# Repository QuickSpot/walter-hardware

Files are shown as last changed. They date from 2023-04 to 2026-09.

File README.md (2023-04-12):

# Walter hardware

## Introduction

In this repository you can find all information about Walter's hardware. The
hardware is designed using KiCad but we also support Altium designer footprints.
Besides footprints you can also find:
 - Datasheets
 - 3D renders
 - Schematics

Datasheets are published as PDF and are constructed using LaTeX. We welcome any
pull request on the datasheets to make sure all information that is required is
present.

## License

All files in this repository are published under the GPLv3 license.

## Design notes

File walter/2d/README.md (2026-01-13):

# Walter 2D for Laser Cut / Housing Prototyping

This folder contains 2D vector files (in mm scale) to assist with laser cutting, CNC routing, or general housing design for the Walter module.

Included files represent the board’s physical outline and can be used to:
- Cut a mounting area or clearance in enclosures
- Add alignment or anchor features for Walter
- Integrate Walter into panel layouts or case designs

## Notes for Use
- All dimensions are in **millimeters (mm)**.
- Files are provided as **vector formats** (`.svg`, `.pdf`, `.dxf`) and should open in most CAD, vector, or laser software.
- You may need to adjust **cut/engrave/stroke settings** depending on your machine or fabrication provider.
  - Red hairlines (0.001 pt) are commonly used for cuts
  - Black fills or blue lines are typically used for engraving
- Always check alignment and scaling before running a final job.

## Related Footprint Info
Walter uses 2.54mm pitch headers with 14 pins per side (see `footprint/README.md` for full part details). The 2D outline does **not** include pin depths or socket clearance—verify fit based on your exact setup.

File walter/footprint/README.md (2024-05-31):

# Walter footprint

Walter uses 2.54mm pin headers with 14 pins on each side. The mounted part is 
Würth Elektronik 61001418221 with a 6mm pin height or a compatible part with 
slightly less high pins.

Walter can be soldered directly onto your design using wave soldering or by
making use of matching sockets. Possible sockets to use are:
 -  Würth Elektronik 61301411821
 -  Multicomp Pro 2212S-14SG-85
 -  Samtec SSW-114-01-T-S

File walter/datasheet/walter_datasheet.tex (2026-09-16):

\documentclass[11pt]{article}

\usepackage[margin=2cm, a4paper]{geometry}	%2cm page margin
\usepackage{fancyhdr}						%use fancy headers
\usepackage{graphicx}						%use images
\usepackage{textcomp}						%used for textdegree command
\usepackage[hidelinks]{hyperref}            %used for clickable references
\usepackage{pgfplots}
\usepackage{tikz}
\pgfplotsset{compat=1.18}

%DPTECHNICS datasheet variables
\newcommand{\dptproduct}{Walter - WiFi/BLE/NB-IoT/LTE-M/GNSS module}

\newcommand{\textoverline}[1]{$\overline{\mbox{#1}}$}

%page footers and headers settings
\pagestyle{fancy}
\fancyhead{}
\fancyfoot{}
\fancyhead[LO,LE]{ {\bf \dptproduct}}
\fancyfoot[R]{\thepage}
\fancyfoot[L]{QuickSpot - A brand of DPTechnics BV}
\renewcommand{\footrulewidth}{0.4pt}
\renewcommand\familydefault{\sfdefault}
\setlength{\parindent}{0pt}

\begin{document}
\begin{titlepage}
\hfill\\

\hfill {\bf \Large  \dptproduct}\\[-3mm]

\hfill {\Large Datasheet} \\[4cm]

\begin{center}
 
\end{center}

\vfill
\rule{487pt}{1pt}

\hfill Revision 1.0 - \today
\end{titlepage}
\section{General information}
Walter is a small-form-factor IoT system-on-module (SoM) that combines a powerful ESP32-S3 system-on-chip (SoC) with a second-generation Sequans GM02SP LTE-M/NB-IoT 5G modem and GNSS receiver. Its ESP32-S3 provides many built-in peripherals as well, including UART, SPI, I²C, CAN, Wi-Fi b/g/n, and Bluetooth 5.

\section{Features}
Walter is based on an ESP32-S3-WROOM-1-N16R2 module with an on-board Sequans GM02SP modem.
This combination makes Walter a unique development board that offers a rich feature-set which include but is not limited to:
\begin{itemize}
	\item CPU: Xtensa Dual-core 32-bit LX7 CPU (ESP32-S3 SoC)
	\item RAM: 2MB (Quad SPI) PSRAM
	\item Flash: 16MB (Quad SPI) Flash memory
	\item WiFi: 150Mbps(n) 802.11 WiFi b/g/n with on-board antenna
	\item LTE: CAT M1/NB1/NB2 (GM02SP module)
	\item GPS: GPS, GNSS Constellation support (GM02SP module)
	\item Bluetooth: 2Mbps Bluetooth 5 (LE), Bluetooth Mesh
	\item 24 physical GPIO pins
	\item Ultra low deep sleep current of 9.8\textmu A
	\item Open source software support for ESP-IDF, Arduino, Micropython and Toit
	\item Certified for CE, FCC, IC, UKCA, New-Zealand and Australia
	\item Solderless integration into any project due to the 2.54mm pin headers
\end{itemize}

\section{Electrical characteristics}
For the most reliable use and stability of the module we advice to use the typical ratings. We do not guarantee the correct functioning of the device outsite the minimum and maxium range of the module. 
\begin{center}
\renewcommand{\arraystretch}{1.5}
\begin{tabular}{|p{5cm}|c|c|c|c|}
\hline
{\bf Parameter} & {\bf Units} & {\bf Minimum rating} & {\bf Typical rating} & {\bf Maximum rating} \\
\hline
\hline
DC Supply Voltage & V & 3.0 & 5.0 & 5.5 \\
\hline
Digital I/O Voltage & V & 2.64 & 3.3 & 3.6 \\
\hline
Power consumption @3.3V & A & -- & -- & 1.5 \\
\hline
3.3V output current & A & -- & -- & 0.25 \\
\hline
Deep sleep current & \textmu A & -- & 9.8 & -- \\
\hline
\end{tabular}
\end{center}

\newpage
\section{Interfaces}
Walter provides a total of 28 physical pins (3 power, 1 strapping pin and 24 I/O pins) to interface with external parts. This chapter provides information about these pins as well as internally connected pins and the testpoints located at the bottom of the board.\\

Power supply pins and their details are available in section \ref{power} about the power characteristics.\\

For more information about specific pins regarding the ESP32-S3 Wroom module or the Sequans GM02SP module, please refer to the datasheet of the corresponding module.

\subsection{Pin Assignment} \label{pin_assigment}

\begin{figure}[h]
    \centering
    
    \caption{Walter pinout (top view)}
    \label{fig:walter_pin_assignment}
\end{figure}
\newpage
\subsubsection{External Pins} \label{external_pins}
Table \ref{table_exteral_pin} contains the description of the physical pins on Walter available on the underside of the board. \\
The order of this table, in reference to the board, is top to bottom and left to right.\\
\renewcommand{\arraystretch}{1.5}
\begin{table}[!h]
\begin{center}
\begin{tabular}{|c|c|c|c|c|p{9.5cm}|}
\hline
{\bf Pin} & {\bf Function} & \multicolumn{1}{c|}{\bf ESP pin} & \multicolumn{1}{c|}{\bf Input/Output} & \multicolumn{1}{c|}{\bf Description} \\
\hline
\hline
1 & RESET & EN & input & ESP32 reset with 10k pullup \\
\hline
2 & IO44/RX0 & RXD0 & bidirectional & ESP32 UART0 Receive \\
\hline
3 & IO43/TX0 & TXD0 & bidirectional & ESP32 UART0 Transmit \\
\hline
4 & \textoverline{DFU}/\textoverline{3V3\_EN} & IO0 & bidirectional & DFU when low on boot and 3V3 output enable \\
\hline
5 & IO12 & IO12 & bidirectional & General purpose I/O \\
\hline
6 & IO11 & IO11 & bidirectional & General purpose I/O \\
\hline
7 & IO13 & IO13 & bidirectional & General purpose I/O \\
\hline
8 & IO38 & IO38 & bidirectional & General purpose I/O \\
\hline
9 & IO39 & IO39 & bidirectional & General purpose I/O \\
\hline
10 & IO40 & IO40 & bidirectional & General purpose I/O \\
\hline
11 & IO41 & IO41 & bidirectional & General purpose I/O \\
\hline
12 & IO42 & IO42 & bidirectional & General purpose I/O \\
\hline
13 & IO2 & IO2 & bidirectional & General purpose I/O \\
\hline
14 & IO1 & IO1 & bidirectional & General purpose I/O \\
\hline
15 & IO4 & IO4 & bidirectional & General purpose I/O \\
\hline
16 & IO5 & IO5 & bidirectional & General purpose I/O \\
\hline
17 & IO6 & IO6 & bidirectional & General purpose I/O \\
\hline
18 & IO7 & IO7 & bidirectional & General purpose I/O \\
\hline
19 & IO15 & IO15 & bidirectional & General purpose I/O \\
\hline
20 & IO16 & IO16 & bidirectional & General purpose I/O \\
\hline
21 & IO17 & IO17 & bidirectional & General purpose I/O \\
\hline
22 & IO18 & IO18 & bidirectional & General purpose I/O \\
\hline
23 & IO8 & IO8 & bidirectional & General purpose I/O \\
\hline
24 & IO9 & IO9 & bidirectional & General purpose I/O \\
\hline
25 & IO10 & IO10 & bidirectional & General purpose I/O \\
\hline
26 & 3V3 OUT & N/A & power output & Switchable 3.3VDC output \\
\hline
27 & GND & GND & power ground & GND connection \\
\hline
28 & VIN & N/A & power input & DC Power input port\\
\hline
\end{tabular}
\caption{\label{table_exteral_pin}Walter pin definitions}
\end{center}
\end{table}
\newpage

\subsubsection{Internal Pins} \label{internal_pins}
Table \ref{table_interal_pin} contains the pin descriptions of the internally connected GPIO pins on Walter. These are necessary for either communication between components on the board or reserved for other purposes and thus not available for external use.

\begin{table}[!h]
    \centering
    \begin{tabular}{|c|p{9.5cm}|}
    \hline
    {\bf ESP pin} & \multicolumn{1}{c|}{\bf Description} \\
    \hline
    \hline
    IO19 & USB D-\\
    \hline
    IO20 & USB D+\\
    \hline
    IO46 & LTE\_WAKE0 \\
    \hline
    IO48 & LTE\_UART0\_TX (See \ref{lte_uart})\\
    \hline
    IO14 & LTE\_UART0\_RX (See \ref{lte_uart})\\
    \hline
    IO21 & LTE\_UART0\_RTS (See \ref{lte_uart})\\
    \hline
    IO47 & LTE\_UART0\_CTS (See \ref{lte_uart})\\
    \hline
    IO45 & LTE\_RESET\\
    \hline
    \end{tabular}
    \caption{\label{table_interal_pin}Walter Internal Pin Definitions}
\end{table}

\newpage
\subsubsection{Testpoints} \label{testpoints}
Walter contains 22 testpoints on the bottom of the board that serve multiple purposes. You can use these pins for debugging, interfacing and/or flashing of the Sequans GM02SP and the ESP32-S3-WROOM module.
\begin{figure}[h]
    \centering
    
    \caption{Walter testpoints}
    \label{fig:testpoints}
\end{figure}

\begin{center}
\begin{tabular}{|c|p{9.5cm}|}
    \hline
    {\bf Number} & \multicolumn{1}{c|}{\bf Description} \\
    \hline
    \hline
    1 & Sequans GM02SP JTAG TDO\\
    \hline
    2 & Sequans GM02SP JTAG TCK\\
    \hline
    3 & Sequans GM02SP JTAG TRSTN\\
    \hline
    4 & Sequans GM02SP JTAG TMS\\
    \hline
    5 & Sequans GM02SP JTAG TDI\\
    \hline
    6 & Sequans GM02SP PS status\\
    \hline
    7 & Sequans GM02SP RES/FFF\_FFH \\
    \hline
    8 & Sequans GM02SP RX0 \\
    \hline
    9 & Sequans GM02SP TX0 \\
    \hline
    10 & Sequans GM02SP TX1 \\
    \hline
    11 & Sequans GM02SP RX1 \\
    \hline
    12 & Sequans GM02SP RX2 \\
    \hline
    13 & Sequans GM02SP CTS0 \\
    \hline
    14 & Sequans GM02SP RTS0 \\ 
    \hline
    15 & Sequans GM02SP CTS1 \\
    \hline
    16 & Sequans GM02SP RTS1 \\
    \hline
    17 & Sequans GM02SP TX2 \\
    \hline
    18 & Walter input power \\
    \hline
    19 & 3V3 output (not switched) \\
    \hline
    20 & Sequans GM02SP 1V8 output \\
    \hline
    21 & Ground \\
    \hline
    22 & ESP32-S3 GPIO3 (strapping pin)\\
    \hline
\end{tabular}
\end{center}

\begin{figure}[h]
    \centering
    
    \caption{Bottom view of the Walter testpoints with their connection names.}
    \label{fig:testpointsnamed}
\end{figure}

\subsubsection{Others}
Not all pins of the ESP32-S3 and Sequans GM02SP on Walter are internally connected, available through physical pins or testpoints. These pins are either reserved for use by the component itself or deemed not necessary to be available externally.

\subsection{Sequans GM02SP UARTs} \label{lte_uart}
The Sequans GM02SP module has 3 hardware UART interfaces. Only UART0 is connected to the ESP32-S3 Wroom Module on Walter as shown in Table \ref{table_interal_pin}. Communication between modules is possible with AT-commands. Please refer to the corresponding AT command reference manual of the Sequans GM02SP for all possible AT-commands. The UARTs have the following functionality by default:
\begin{itemize}
	\item UART0 (115200@8N1 with HW handshaking): used for AT commands.
	\item UART1 (921600@8N1 with HW handshaking): used for manual firmware updates and/or custom software installation.
	\item UART2 (115200@8N1 no HW handshaking): console log output.
\end{itemize}

Please not that any UART host should be connected as follows:
\begin{itemize}
	\item \verb+RX <-> RX+
	\item \verb+TX <-> TX+
	\item \verb+RTS <-> RTS+
	\item \verb+CTS <-> CTS+
\end{itemize}
\section{Electrical and RF Characteristics} \label{power_rf_characteristics}
\subsection{Power} \label{power}
\subsubsection{Power Input}
Walter can be powered either by connecting a USB-C cable or via the VIN pin (see pinout \ref{external_pins}).\\

\textbf{DO NOT} power Walter with both the USB-C connection and the VIN-pin! This can lead to seriously damaging the board and external peripherals connected to it! To minimize losses the USB-C power input and Vin input pin are directly connected to each other. If you want to debug your application through USB-C while Walter is plugged into a carrier board we advise you to modify a USB-C cable by cutting the power lead. 

\subsubsection{Power Output}
Walter contains a Texas Instruments TPS6208833 DC-DC Converter which takes power from either the USB-C port or the VIN-pin and converts it to a regulated +3.3VDC supply. The maximum load on the 3.3VDC output is 250mA. 

\subsubsection{Power Consumption}
\subsection{GPIO} \label{gpio}
All GPIO pins exposed via the physical pin headers on Walter are 3.3V resistant. If you want to connect 5V or other forms of logic, please use a suitable logic level converter or voltage divider.\\

Please reference the corresponding datasheets for all minimum, maximum and typical ratings of I/O pins of the ESP32-S3-WROOM or Sequans GM02SP Modules that may or may not be exposed on the Walter Development Board.

\newpage
\section{Mechanical information}
\begin{figure}[h]
    \centering
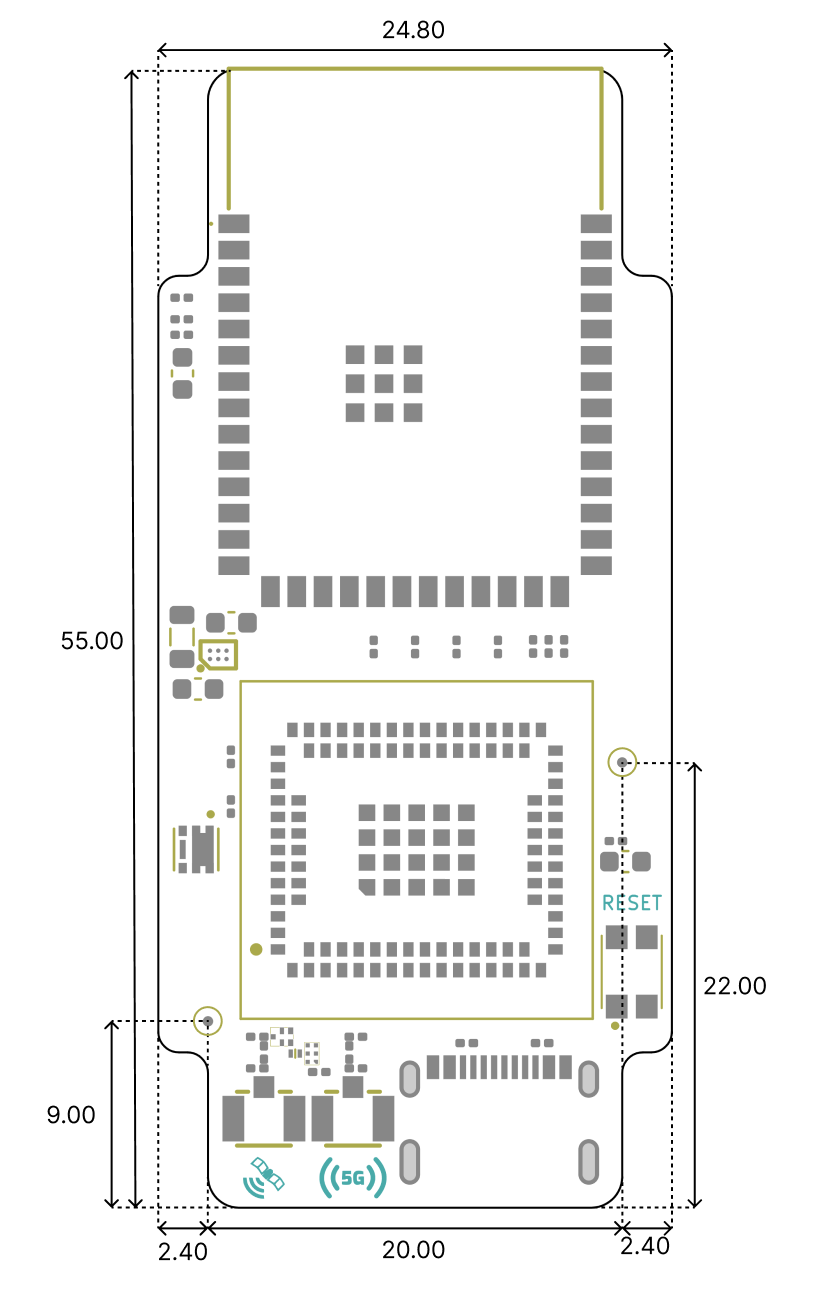
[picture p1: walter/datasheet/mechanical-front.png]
    
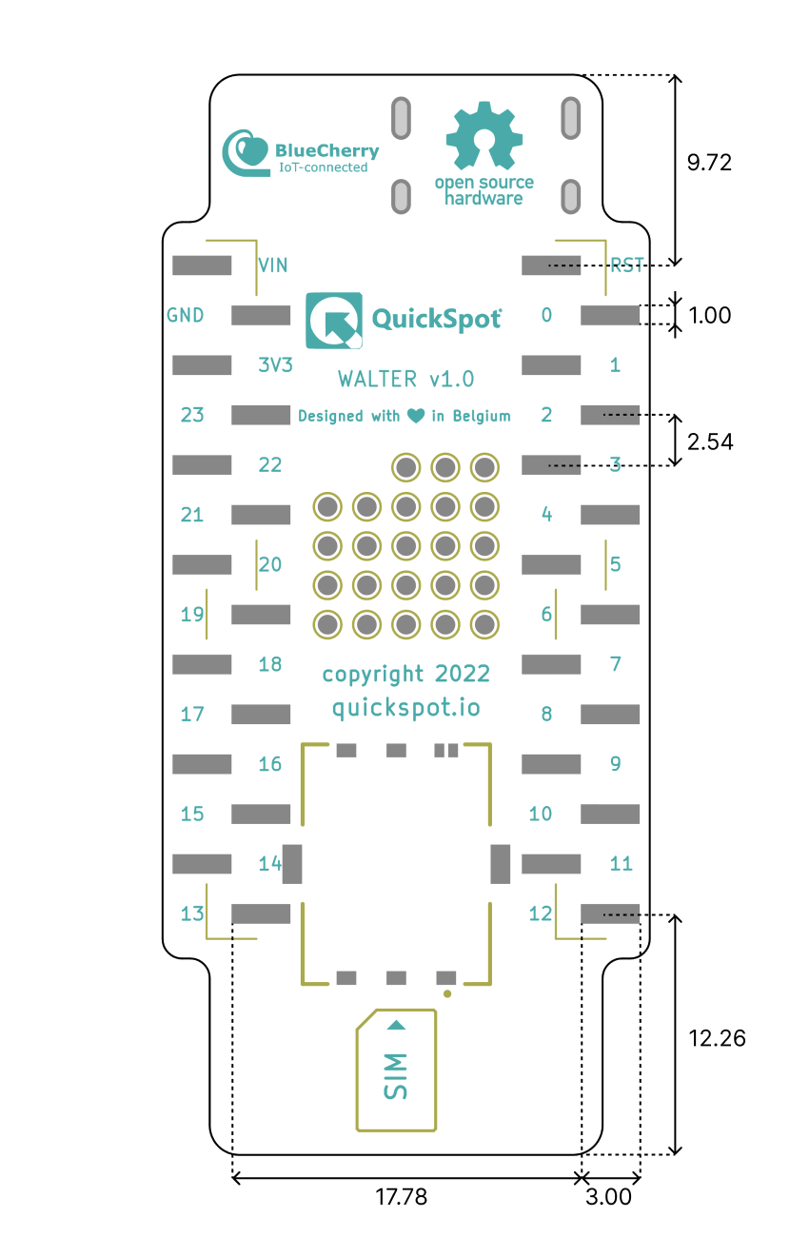
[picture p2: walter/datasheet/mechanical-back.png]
    
    \caption{Mechanical Drawing Front and Rear View - Unit in mm}
    \label{fig:mechanical_front}
\end{figure}

\section{Software}
\subsection{Libraries and frameworks from QuickSpot}

Every Walter comes pre-flashed with an example application. This demonstration firmware requires the LTE and GNSS antennas to be connected and performs the following tasks: 

\begin{enumerate}
    \item Configure the modem for LTE-M connectivity with the network-pushed APN.
    \item Check and update the GNSS assistance data if required.
    \item Try to establish a GNSS fix. The firmware attempts this up to 5 times, with a maximum duration of approximately 66 seconds per attempt.
    \item Upload the data to the \href{https://walterdemo.quickspot.io}{walterdemo.quickspot.io} portal.
\end{enumerate}

To use this pre-flashed demonstrator, install the LTE and GNSS antennas and insert a SIM card that supports LTE-M. Make sure the GNSS antenna has a clear view of the sky and allow Walter about 10 minutes to connect and upload its first message. Every Walter identifies itself using the MAC address printed on the bag in which it was shipped. \\

If you do not want to upload your position to the public \href{https://walterdemo.quickspot.io}{walterdemo.quickspot.io} platform, or if you want to run your own code, which is what Walter is designed for, you can flash your own firmware. You can easily program and upload your own firmware for Walter using Arduino, ESP-IDF, MicroPython or Zephyr. Please refer to the "Getting Started with Walter" guide available on our GitHub to get you up and running fast.

\subsection{AT commands}

The full set of supported AT commands can be found in the documentation of the Sequans GM02SP. This can be downloaded from this link: \href{https://www.renesas.com/eu/en/document/mah/ryz024-modules-command-users-manual?language=en}{https://www.renesas.com/eu/en/document/mah/ryz024-modules-command-users-manual?language=en}.

\subsection{Manual SFU of the GM02SP}

The second hardware UART of the GM02SP, namely \verb+UART1+, is used for manual firmware upgrades. To do a manual serial SFU of the GM02SP in Walter you must connect \verb+UART1+ via the testpads on the bottom of the module. Use an FTDI UART and make the following connections:
\begin{itemize}
	\item \verb+Walter RX1 <-> FTDI RX+
	\item \verb+Walter TX1 <-> FTDI TX+
	\item \verb+Walter RTS1 <-> FTDI RTS+
	\item \verb+Walter CTS1 <-> FTDI CTS+
	\item \verb+Walter GND <-> FTDI GND+
	\item \verb$Walter Vin <-> +5VDC$
\end{itemize}
Make sure that the 5V power source which is powering Walter and the FTDI share a common ground. To enable smooth updating it is best not to connect the USB-C on Walter to the computer on which the SFU software is running. Now follow the instructions which are bundled with the SFU release.

\section{Operating conditions}
The module can operate in a wide range of temperatures and conditions. The following are guidelines in which the module is guaranteed to work correctly. 
\begin{center}
\renewcommand{\arraystretch}{1.5}
\begin{tabular}{|p{5cm}|c|c|c|c|}
\hline
{\bf Parameter} & {\bf Units} & {\bf Minimum rating} & {\bf Typical rating} & {\bf Maxium rating} \\
\hline
\hline
Working temperature & \textdegree C & -40 &  & 85 \\
\hline
Storage temperature & \textdegree C & -40 &  & 100 \\
\hline
Humidity & \%RH & 10 &  & 90 \\
\hline
Storage humidity & \%RH & 5 & & 90 \\
\hline
\end{tabular}
\end{center}
Please note that no condensation may occur on the PCB and components. 

\section{Manufacturing information: soldering and MSL}
The Walter module can be assembled using either a reflow soldering process with pin-in-paste technology or a wave soldering process.\\

When the module is subjected to reflow soldering, it shall be handled in accordance with Moisture Sensitivity Level 3 (MSL 3) requirements. MSL handling is not required for wave soldering processes in which the module body temperature remains below 125$^\circ$C.\\

For reflow soldering, the profile shown in Figure~\ref{fig:reflow-profile} is recommended. This profile is suitable for use with SAC305 lead-free solder paste.

\begin{figure}[htbp]
    \centering

    \begin{tikzpicture}
    \begin{axis}[
        width=0.95\textwidth,
        height=0.55\textwidth,
        xmin=0,
        xmax=360,
        ymin=20,
        ymax=260,
        xlabel={Time [s]},
        ylabel={Temperature [$^\circ$C]},
        xtick={0,60,120,180,240,300,360},
        ytick={25,50,100,150,180,200,217,240,260},
        grid=major,
        grid style={gray!20},
        axis line style={black!70},
        tick style={black!70},
        legend style={
            at={(0.03,0.58)},
            anchor=west,
            draw=none,
            fill=white,
            font=\small
        },
        clip=false
    ]

    % --------------------------------------------------------
    % Target reflow profile
    % --------------------------------------------------------
    \addplot[
        very thick,
        smooth
    ]
    coordinates {
        (0,25)
        (60,85)
        (120,150)
        (180,180)
        (205,200)
        (220,217)
        (240,233)
        (252,240)
        (264,238)
        (280,225)
        (288,217)
        (310,160)
        (330,100)
        (360,50)
    };

    \addlegendentry{Target reflow profile}

    % --------------------------------------------------------
    % SAC305 liquidus
    % --------------------------------------------------------
    \addplot[
        dashed,
        thick
    ]
    coordinates {
        (0,217)
        (360,217)
    };

    \node[
        anchor=north east,
        font=\small,
        fill=white,
        inner sep=2pt,
        yshift=-3pt
    ] at (axis cs:352,217)
    {SAC305 liquidus: 217\,°C};

    % --------------------------------------------------------
    % Maximum package body temperature
    % --------------------------------------------------------
    \addplot[
        dashed,
        very thick
    ]
    coordinates {
        (0,245)
        (360,245)
    };

    \node[
        anchor=south east,
        font=\small\bfseries,
        fill=white,
        inner sep=2pt,
        yshift=2pt
    ] at (axis cs:352,245)
    {Maximum body temperature: 245\,°C};

    % --------------------------------------------------------
    % Peak temperature marker
    % --------------------------------------------------------
    \addplot[
        only marks,
        mark=*,
        mark size=2.5pt
    ]
    coordinates {
        (252,240)
    };

    \node[
        anchor=north east,
        font=\small,
        fill=white,
        inner sep=2pt,
        xshift=-4pt,
        yshift=-6pt
    ] at (axis cs:252,240)
    {Target peak: 240\,°C};

    % --------------------------------------------------------
    % Time above liquidus
    % --------------------------------------------------------
    \draw[
        <->,
        thick
    ]
    (axis cs:220,198)
    --
    (axis cs:288,198);

    \node[
        anchor=north,
        font=\small,
        fill=white,
        inner sep=1pt,
        yshift=-2pt
    ] at (axis cs:254,198)
    {Time above 217\,°C $\approx$ 68 s};

    % --------------------------------------------------------
    % Soak region
    % --------------------------------------------------------
    \draw[
        <->,
        thick
    ]
    (axis cs:120,140)
    --
    (axis cs:180,140);

    \node[
        anchor=north,
        font=\small,
        fill=white,
        inner sep=1pt,
        yshift=-2pt
    ] at (axis cs:150,140)
    {Soak region};

    \end{axis}
    \end{tikzpicture}

    \caption{
        Recommended lead-free reflow profile for the Walter module.
    }

    \label{fig:reflow-profile}
\end{figure}

\section{Prohibited Use and Resale Statement}
This electronics manual serves as a legal document outlining the terms of use and resale of the electronics herein described. By accessing, using, or reselling these electronics, you agree to abide by the terms outlined herein.

\subsection{Prohibition on Resale to Third Countries}
Users of these electronics are strictly prohibited from reselling them to third countries listed under the Export Control Classification Number (ECCN) or mentioned in Section 2.903 of the Federal Communications Commission (FCC) rules. Any such resale is considered a violation of export control regulations and may result in legal consequences.

\subsection{Prohibition on Military Use}
These electronics may not be used for military purposes without the prior written consent of the manufacturer. Any unauthorized use for military applications is strictly prohibited and may result in legal action.

\subsection{Compliance with Applicable Local Laws}
Users of these electronics are obligated to comply with all applicable local laws and regulations. This includes but is not limited to Section 5301 of the Anti-Drug Abuse Act of 1988, 21 U.S.C. 862. Any use of these electronics for purposes contrary to local law is strictly prohibited.

\subsection{Manufacturer's Liability}
The manufacturer holds no liability for any misuse or unauthorized use of these electronics. Users assume full responsibility for their actions and agree to indemnify and hold harmless the manufacturer from any claims, damages, or liabilities arising from such misuse.

\section{Certification}
Walter has the following certifications:
\begin{itemize}
	\item FCC: 2BDGUWALTER
	\item ISED: Contains 21098-ESPS3WROOM1 and 12732A-GM02SA
	\item CE: European Economic Area
	\item UKCA: Great Britain
	\item RCM: New Zealand and Australia
\end{itemize}

\subsection{Federal Communication Commission Interference Statement}
This device complies with Part 15 of the FCC Rules. Operation is subject to the following two conditions:
\begin{enumerate} 
	\item This device may not cause harmful interference.
	\item This device must accept any interference received, including interference that may cause undesired operation.
\end{enumerate}

{\bf CAUTION}: Changes or modifications not expressly approved by the party responsible for compliance could void the user’s authority to operate the equipment. \\

{\bf NOTE}: This equipment has been tested and found to comply with the limits for a Class B digital device, pursuant to Part 15 of the FCC Rules. These limits are designed to provide reasonable protection against harmful interference in a residential installation. This equipment generates, uses and can radiate radio frequency energy and, if not installed and used in accordance with the instructions, may cause harmful interference to radio communications. However, there is no guarantee that interference will not occur in a particular installation. If this equipment does cause harmful interference to radio or television reception, which can be determined by turning the equipment off and on, the user is encouraged to try to correct the interference by one or more of the following measures:
\begin{itemize}
	\item Reorient or relocate the receiving antenna.
	\item Increase the separation between the equipment and receiver.
	\item Connect the equipment into an outlet on a circuit different from that to which the receiver is connected.
	\item Consult the dealer or an experienced radio/TV technician for help.
\end{itemize}
\subsection{RF warning statement}
To comply with FCC RF exposure compliance requirements, the antennas used for this transmitter must be installed to provide a separation distance of at least 20 cm from all persons and must not be co–located or operating in conjunction with any other antenna or transmitter.

\subsection{OEM integrator conditions}
This device is intended only for OEM integrators under the following conditions:
\begin{enumerate}
	\item The antenna must be installed such that 20 cm is maintained between the antenna and users.
	\item The transmitter module may not be co–located with any other transmitter or antenna.
\end{enumerate}

As long as the two conditions above are met, further transmitter tests will not be required. However, the OEM integrator is still responsible for testing their end–product for any additional compliance requirements required with this module installed. To ensure compliance with all non–transmitter functions the host manufacturer is responsible for ensuring compliance with the module(s) installed and fully operational. For example, if a host  was previously authorized as an unintentional radiator under the Declaration of Conformity procedure without a 
transmitter certified module and a module is added, the host manufacturer is responsible for ensuring that after the module is installed and operational the host continues to be compliant with the Part 15B unintentional radiator requirements.\\

The module is limited to OEM installation only. The module is limited to installation in a fixed application. We hereby acknowledge our responsibility to provide guidance to the host manufacturer in the event that they require assistance for ensuring compliance with the Part 15 Subpart B requirements.\\

{\bf IMPORTANT NOTE}: In the event that these conditions cannot be met (for example certain laptop configurations or co–location with another transmitter), then the FCC authorization is no longer considered valid and the FCC ID cannot be used on the final product. In these circumstances, the OEM integrator will be responsible for re–evaluating the end product (including the transmitter) and obtaining a separate FCC authorization. 

\subsection{Antennas}
The maximum LTE antenna gain values (accounting for cable attenuation) to comply with the FCC and RED maximum ERP/EIRP limits and with RF Exposure rules:
\begin{itemize}
	\item LTE band 2 (1900 PCS): 8.0 dBi
	\item LTE band 4 (AWS-1): 5.0 dBi
	\item LTE band 5 (850): 9.4 dBi
	\item LTE band 12 (700a): 8.6 dBi
	\item LTE band 13 (700c): 9.1 dBi
	\item LTE band 17 (700b): 8.7 dBi
	\item LTE band 25 (1900+): 8.0 dBi
	\item LTE band 66 (AWS-3): 5.0 dBi
\end{itemize}

An example of an approved LTE antenna is the Taoglas FXUB63.07.0150C. \\

An example of an approved GNSS antenna is the Taoglas FXP611.07.0092C.

\subsection{Limited module procecures}
Not applicable

\subsection{Trace antenna designs}
Not applicable

\subsection{End product labelling}
This transmitter module is authorized only for use in device where the antenna may be installed such that 20 cm must be maintained between the antenna and users. The final end product must be labelled in a visible area with the following: “Contains FCC ID: 2BDGUWALTER”. The grantee’s FCC ID can be used only when all FCC compliance requirements are met. The following FCC part 15.19 statement has to also be available on the label:

\begin{verbatim}
This device complies with Part 15 of FCC rules. Operation is subject to the
following two conditions:
1. this device may not cause harmful interference and
2. this device must accept any interference received,
   including interference that may cause undesired operation.
\end{verbatim}

\subsection{Manual information to the end user}
The OEM integrator has to be aware not to provide information to the end user regarding how to install or remove this RF module in the user’s manual of the end product which integrates this module. In the user manual of the end product, the end user has to be informed that the equipment complies with FCC radio–frequency exposure guidelines set forth for an uncontrolled environment. The end user has to also be informed that any changes or modifications not expressly approved by the manufacturer could void the user’s authority to operate this equipment. The end user manual shall include all required regulatory information/warning as show in this manual. The maximum operating ambient temperature of the equipment declared by the manufacturer is -40\textdegree C to +85\textdegree C.

\section{Orderable part numbers}
\begin{center}
\renewcommand{\arraystretch}{1.5}
\begin{tabular}{|l|l|l|l|l|}
\hline
{\bf Part number} & {\bf Description} & {\bf HS} & {\bf JPHTS} & {\bf ECCN} \\
\hline
\hline
P000000100 & 16MiB Flash, 2MiB PSRAM, PCB antenna & 851762 & 851762090 & 5A992.C \\
\hline
P000000118 & 16MiB Flash, 8MiB PSRAM, PCB antenna & 851762 & 851762090 & 5A992.C \\
\hline
P000000119 & 16MiB Flash, 8MiB PSRAM, u.FL WiFi/BLE & 851762 & 851762090 & 5A992.C \\
\hline
\end{tabular}
\end{center}

\section{Legal information}
This module is manufactured by DPTechnics bv. We are not responsible for any product this module is part of. This datasheet is made with great care for detail but it is possible the datasheet will be updated with more accurate data in te future. Users of DPTechnics bv products can contact us by letter, telephone or email. For inquiries regarding the permissible use, resale, or any other questions related to these electronics, please contact the manufacturer. By using or reselling these electronics, you acknowledge that you have read and understood the terms outlined in this manual and agree to fully comply with them.\\

\noindent DPTechnics bv\\
Westkapellestraat 396/44\\
8300 Knokke-Heist\\
Belgium\\

VAT No: BE0682 598 007\\

\noindent Tel: +32(0)50 62 13 79\\
Email: info@quickspot.io\\
Web: https://www.quickspot.io
\end{document}

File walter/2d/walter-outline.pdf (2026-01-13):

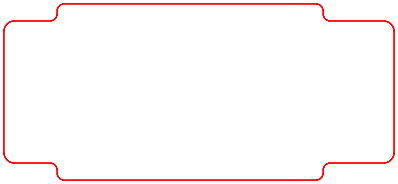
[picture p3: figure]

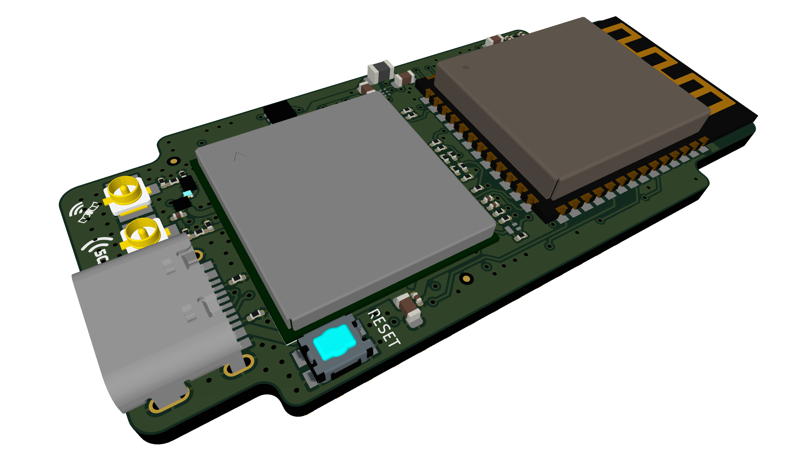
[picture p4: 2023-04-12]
walter/3d/render.png

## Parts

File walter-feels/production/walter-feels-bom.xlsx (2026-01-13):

Designator | Value | Description | Footprint | Qty | Manufacturer | Part Number
C1, C2, C58, C72, C73, C74, C75, C76 | 100µF | 100μF ±20%, 6.3V, X5R, 1210 MLCC | 1210 | 8 | Any | Any
C3 | 2200pF | 2200pF ±10%, 50V, X7R, 0603 MLCC | 0603 | 1 | Any | Any
C4 | 100pF | 100pF ±5%, 50V, C0G, 0603 MLCC | 0603 | 1 | Any | Any
C5, C8, C10, C11, C18, C21, C24, C62, C70, C79 | 10µF | 10µF ±10%, 50V, X5R, 1206 MLCC | 1206 | 10 | Any | Any
C6, C34, C35 | 10nF | 10nF ±10%, 50V, X7R, 0603 MLCC | 0603 | 3 | Any | Any
C7, C17, C22, C38, C39, C40, C41, C42, C43, C44, C45, C47, C48, C49, C50, C51, C52, C57, C61, C64, C68, C71, C78, C83 | 0.1µF | 0.1µF ±10%, 50V, X7R, 0603 MLCC | 0603 | 24 | Any | Any
C9, C63, C66 | 0.22μF | 0.22μF ±10%, 25V, X7R, 0603 MLCC | 0603 | 3 | Any | Any
C12, C15 | 1000pF | 1000pF ±10%, 50V, X7R, 0603 MLCC | 0603 | 2 | Any | Any
C13 | 0.470µF | 0.470µF ±10%, 25V, X7R, 0603 MLCC | 0603 | 1 | Any | Any
C14, C20 | 0.33μF | 0.33μF ±10%, 25V, X7R, 0603 MLCC | 0603 | 2 | Any | Any
C16 | 2.2μF | 2.2μF ±10%, 16V, X5R, 0603 MLCC | 0603 | 1 | Any | Any
C19, C23, C25, C27, C29, C59, C77 | 1μF | 1μF ±10%, 50V, X5R, 0603 MLCC | 0603 | 7 | Any | Any
C26, C28, C30, C31, C32, C33, C53 | 33µF, 35V | 33μF ±20%, 35V, Polymer Tantalum Capacitor | 2917 | 7 | Kyocera AVX | TCJE336M035R0055
C46 | 33nF | 33nF ±10%, 50V, X7R, 0603 MLCC | 0603 | 1 | Any | Any
C60 | 4.7μF | 4.7μF ±10%, 16V, X5R, 0603 MLCC | 0603 | 2 | Any | Any
C65 | 22nF | 22nF ±10%, 50V, X7R, 0603 MLCC | 0603 | 1 | Any | Any
C67 | 1200pF | 1200pF ±10%, 50V, X7R, 0603 MLCC | 0603 | 1 | Any | Any
C80 | 4700pF | 4700pF ±10%, 50V, X7R, 0603 MLCC | 0603 | 1 | Any | Any
C81, C82 | 18pF | 18pF ±5%, 50V, C0G, 0603 MLCC | 0603 | 2 | Any | Any
D1 |  | 80V, 0.3A, Fast switching diode | DFN-2 | 1 | Diodes Incorporated | 1N4448HLP-7
D2 | 5.6V | 5.6V, 225mW, Zener diode | SOT-23 | 1 | Onsemi | BZX84C5V6LT1G
D3 |  | 25V, 230W, CAN-bus TVS diode | SOT-23 | 1 | STMicroelectronics | ESDCAN01-2BLY
D4, D5 | 8.2V | 8.2V, 0.2W, Zener diode | SOD-523 | 2 | Onsemi | MM5Z8V2T1G
D6 |  | TVS Diode array | 10-UFDFN | 1 | Diodes Incorporated | D3V3X4U10LP-7
F1, F2 | 5A Slow | 5A, 32VDC, Slow, 1206 Fuse | 1206 | 2 | Littelfuse | 0407005.WR.
IC1 |  | Multichemistry buck battery charger controller with digital telemetry | QFN-38 | 1 | Analog Devices | LTC4015EUHF#PBF
J1 |  | Micro-SD card slot | SMT | 1 | Wurth Electronics | 693072010801
J2, J3 |  | 1 row, 2 position, Spring clamp terminal block | THT | 2 | Phoenix Contact | 1071010
J4, J5 |  | 1 row, 9 position, Spring clamp terminal block | THT | 2 | Phoenix Contact | 1990070
J6 |  | 1 row, 4 position, 2.54mm male THT pin header | THT | 1 | Any | Any
J7, J8 |  | 1 row, 14 position, 8.5H, 2.54mm female THT pin header receptacle | THT | 2 | Any | Any
L1 | 10μH | 10μH ±20%, 17A Irms, 25A Isat, 11.6mΩ DCR, Power inductor | SMT | 1 | Bourns | SRP1770C-100M
L2 | 3.3μH | 3.3μH ±20%, 18A Irms, 30A Isat, 5.7mΩ DCR, Power inductor | SMT | 1 | Pulse Elec | PM4343.332NLT
L3 | 10μH | 10μH ±20%, 2.7A Irms, 1.9A Isat, 48mΩ DCR, Power inductor | SMT | 1 | Bourns | SRR7045-100M
L4 |  | 2.8kΩ @ 10MHz, 51μH @ 100kHz, 1Ω DCR, common mode filter | SMT | 1 | TDK | ACT45B-510-2P-TL003
Q1 |  | 40V, 12A, 10mΩ, dual N-channel power MOSFET | Power-33 | 1 | Onsemi | FDMC8030
Q2 |  | 40V, 14A, 9.7mΩ, N-channel MOSFET | Power-33 | 1 | Onsemi | FDMC8327L
Q3 |  | 40V, 18A, 25mΩ, P-channel MOSFET | PowerPAK-1212-8 | 1 | Vishay Intertech | SI7611DN-T1-GE3
Q4, Q6 |  | 30V, 25A, 15.1mΩ, N-channel MOSFET | 6-WSON | 2 | Texas Instruments | CSD17318Q2
Q5 |  | 20V, 9A, 16mΩ, P-channel MOSFET | UDFN-2020-6 | 1 | Diodes Incorporated | DMP2021UFDE-7
R1, R2 | 45.3kΩ | 45.3kΩ ±1%, 100mW, 50V, 0603 resistor | 0603 | 2 | Any | Any
R3, R23 | 64.9kΩ | 64.9kΩ ±1%, 100mW, 50V, 0603 resistor | 0603 | 2 | Any | Any
R4, R5, R8, R11, R26, R29, R30, R31, R32, R33 | 10kΩ | 10kΩ ±1%, 100mW, 50V, 0603 resistor | 0603 | 10 | Any | Any
R6 | 200Ω | 200Ω ±1%, 100mW, 50V, 0603 resistor | 0603 | 1 | Any | Any
R7 | 301kΩ | 301kΩ ±1%, 100mW, 50V, 0603 resistor | 0603 | 1 | Any | Any
R9, R15 | 60.4Ω | 60.4Ω ±1%, 100mW, 50V, 0603 resistor | 0603 | 2 | Any | Any
R10 | 95.3kΩ | 95.3kΩ ±1%, 100mW, 50V, 0603 resistor | 0603 | 1 | Any | Any
R12 | 10kΩ | 10kΩ ±1%, 100mW, 50V, 3380K ±1%, 0603 NTC resistor | 0603 | 1 | Any | Any
R13 | 0.003Ω | 0.003Ω ±1%, 1W, 1206 current sensing resistor | 1206 | 1 | Susumu | KRL3216T4-M-R003-F-T1
R14 | 0.004Ω | 0.004Ω ±1%, 1W, 1206 current sensing resistor | 1206 | 1 | Susumu | KRL3216T4-M-R004-F-T1
R16, R17, R18 | 8.2MΩ | 8.2MΩ ±1%, 100mW, 50V, 0603 resistor | 0603 | 3 | Any | Any
R19, R21 | 510Ω | 510Ω ±1%, 100mW, 50V, 0603 resistor | 0603 | 2 | Any | Any
R20 | 200kΩ | 200kΩ ±1%, 100mW, 50V, 0603 resistor | 0603 | 1 | Any | Any
R22 | 75kΩ | 75kΩ ±1%, 100mW, 50V, 0603 resistor | 0603 | 1 | Any | Any
R24 | 3.48MΩ | 3.48MΩ ±1%, 100mW, 50V, 0603 resistor | 0603 | 1 | Any | Any
R25 | 402kΩ | 402kΩ ±1%, 100mW, 50V, 0603 resistor | 0603 | 1 | Any | Any
R27 | 1MΩ | 1MΩ ±1%, 63mW, 50V, 0603 resistor | 0603 | 1 | Any | Any
R28 | 187kΩ | 187kΩ ±1%, 100mW, 50V, 0603 resistor | 0603 | 1 | Any | Any
U2 |  | 250kbps, RS232 transceiver | TSSOP-16 | 1 | Texas Instruments | MAX3221IPWR
U3 |  | 2.5V-5.5V, 0.5A, 170mΩ power distribution switch | SOT-23-5 | 1 | Microchip | MIC2005A-2YM5-TR
U4 |  | 50Mbps, RS485 transceiver | SOIC-8 | 1 | Texas Instruments | THVD1450DR
U5, U6 |  | Level shifter | SOT-23-5 | 2 | Texas Instruments | SN74LV1T126DBVR
U7 |  | Temperature and humidity sensor | WSON-6 | 1 | Texas Instruments | HDC1080DMBR
U8 |  | Barometric pressure sensor | LGA-10 | 1 | STMicroelectronics | LPS22HBTR
U9 |  | Accelerometer and Gyroscope | LGA-14 | 1 | STMicroelectronics | LSM6DSM
U11 |  | 2.5V-26V, low Iq, DC-DC buck/boost converter | LQFN-28 | 1 | Analog Devices | LT3120JV#PBF
U12 |  | 1.8V-5.5V, 1A, DC-DC boost converter | DFN-8-EP | 1 | Analog Devices | MAX17291ATA+T
U14 |  | 1Mbps CAN-bus transceiver | SOIC-8 | 1 | Texas Instruments | SN65HVDA1050AQDRQ1

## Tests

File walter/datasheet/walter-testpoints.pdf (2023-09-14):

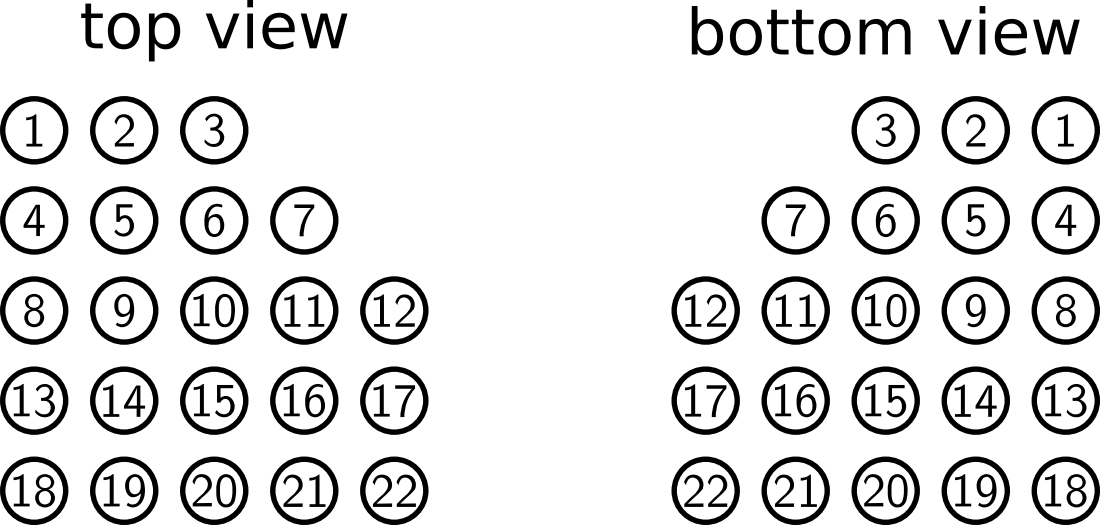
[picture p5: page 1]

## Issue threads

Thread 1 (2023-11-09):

Why not connecting PCM pins?

X-Ryl669, 2023-11-09:
Looking at the schematic, I'm seeing that you're not connecting the PCM pins. That's a shame, since being able to place a call and answer it would be very useful too. Since ESP32 support I2S (I haven't checked the PCM format is the same), this would have been possible and very compact.

Can you explain your decision and if you can change that?

daanpape, 2023-11-09:
Hi,

At this point in time we cannot do any hardware changes because the board is currently in the process of being certified by the accredited laboratory. We are currently also not aware of audio being available in the standardized and certified GM02SP firmware. This led to the decision to keep the ESP32 I/O pins free for the user's application.

Kind regards,
Daan

Closed 2023-11-09.

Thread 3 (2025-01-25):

GM02SP 1.8V Logic and ESP32 3.3V Logic matching

radiolyc, 2025-01-25:
Hi! Thanks for the open schematic of Walter board.
### Description
As I see some signals with 1.8V logic from **GM02SP** connected directly to the **ESP32-S3**:
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

[](https://github.com/QuickSpot/walter-hardware/blob/main/walter/schematic/schematic-v1.6.pdf
)
According to the datasheet _HIGH_ level of the **ESP32-S3** is 0.75*VCC, so when:
VCC=3.3V; HIGH=0.75x3.3V=2.475V;

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

So, technically using it with 1.8V logic from **GM02SP** could cause problems, because 1.8V < 2.475V

e.g. Official **SEQUANS "NEKTAR" MODULE** uses voltage translator between 1.8V and 3.3V rails:

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

SCH-HWPT011B8_0_2022-08-24.pdf
### Question
Was this done intentionally for BOM and board size optimization?
Were there any problems with correct reading signals on the **ESP32-S3** side?

daanpape, 2025-01-25:
Hi,

The schematic is indeed optimized in order for the module to consume as less deep sleep current as possible. We have therefore checked our schematic together with Sequans. The GM02SP pins are 3.3V tolerant which means that the 3.3V output of the ESP32-S3 doesn't hurt the Sequans modem.

For the inputs we have done extensive testing on the pins between the operating temperature range and this with various ESP32-S3-WROOM modules. We concluded that the 1.8V coming from the GM02SP is sufficient to drive the UART input pins reliably in all operating temperatures. This allowed us to save another 5 to 6 uA in deep sleep current.

I hope this clarifies our choice.

radiolyc, 2025-01-28:
Thank you for such a comprehensive answer)

Closed 2025-01-28.

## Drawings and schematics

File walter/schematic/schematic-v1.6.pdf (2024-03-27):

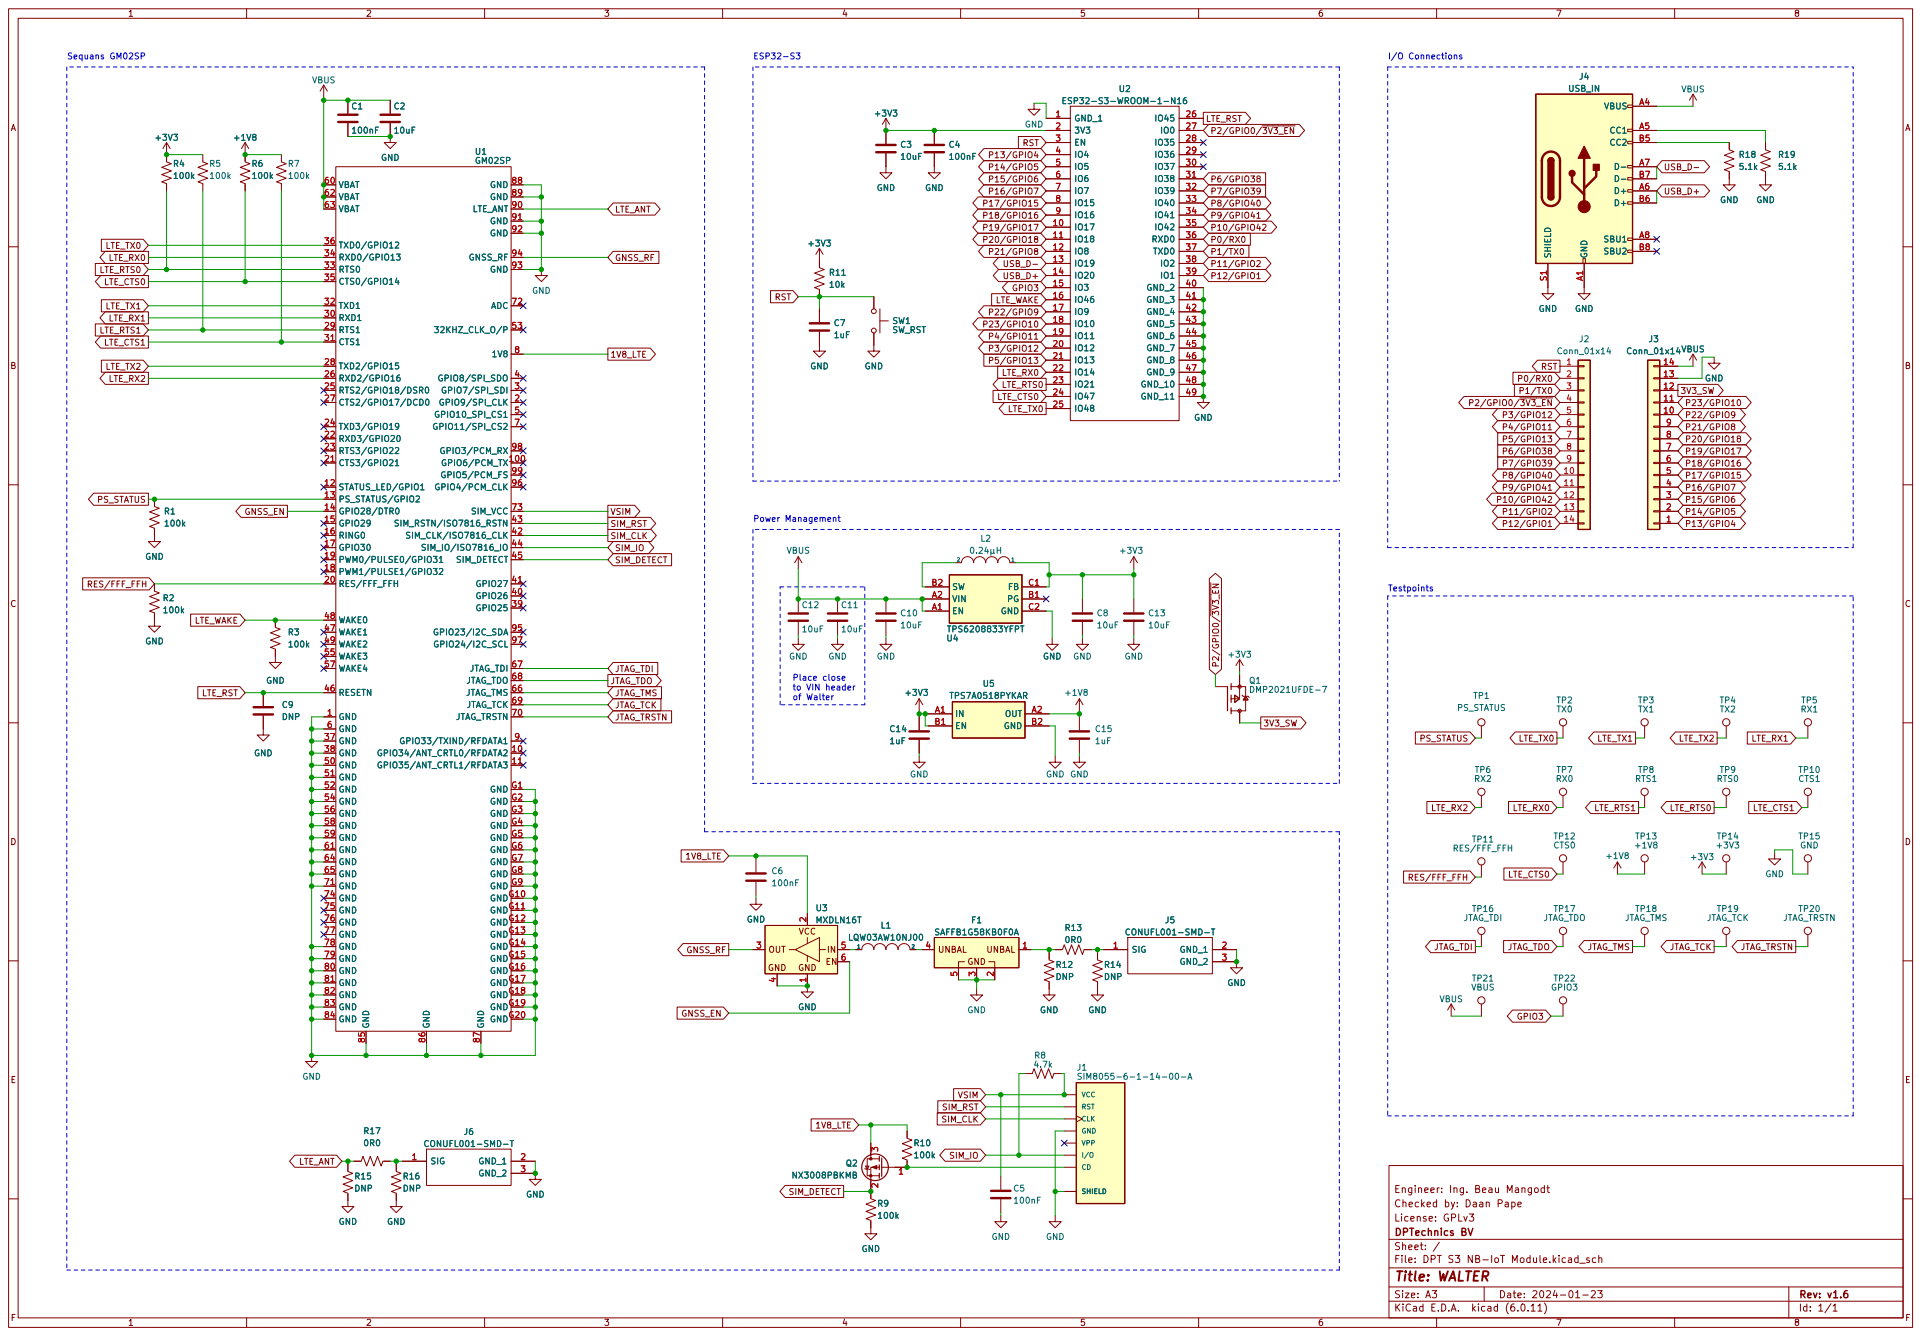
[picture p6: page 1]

to VIN header of Walter Power Management

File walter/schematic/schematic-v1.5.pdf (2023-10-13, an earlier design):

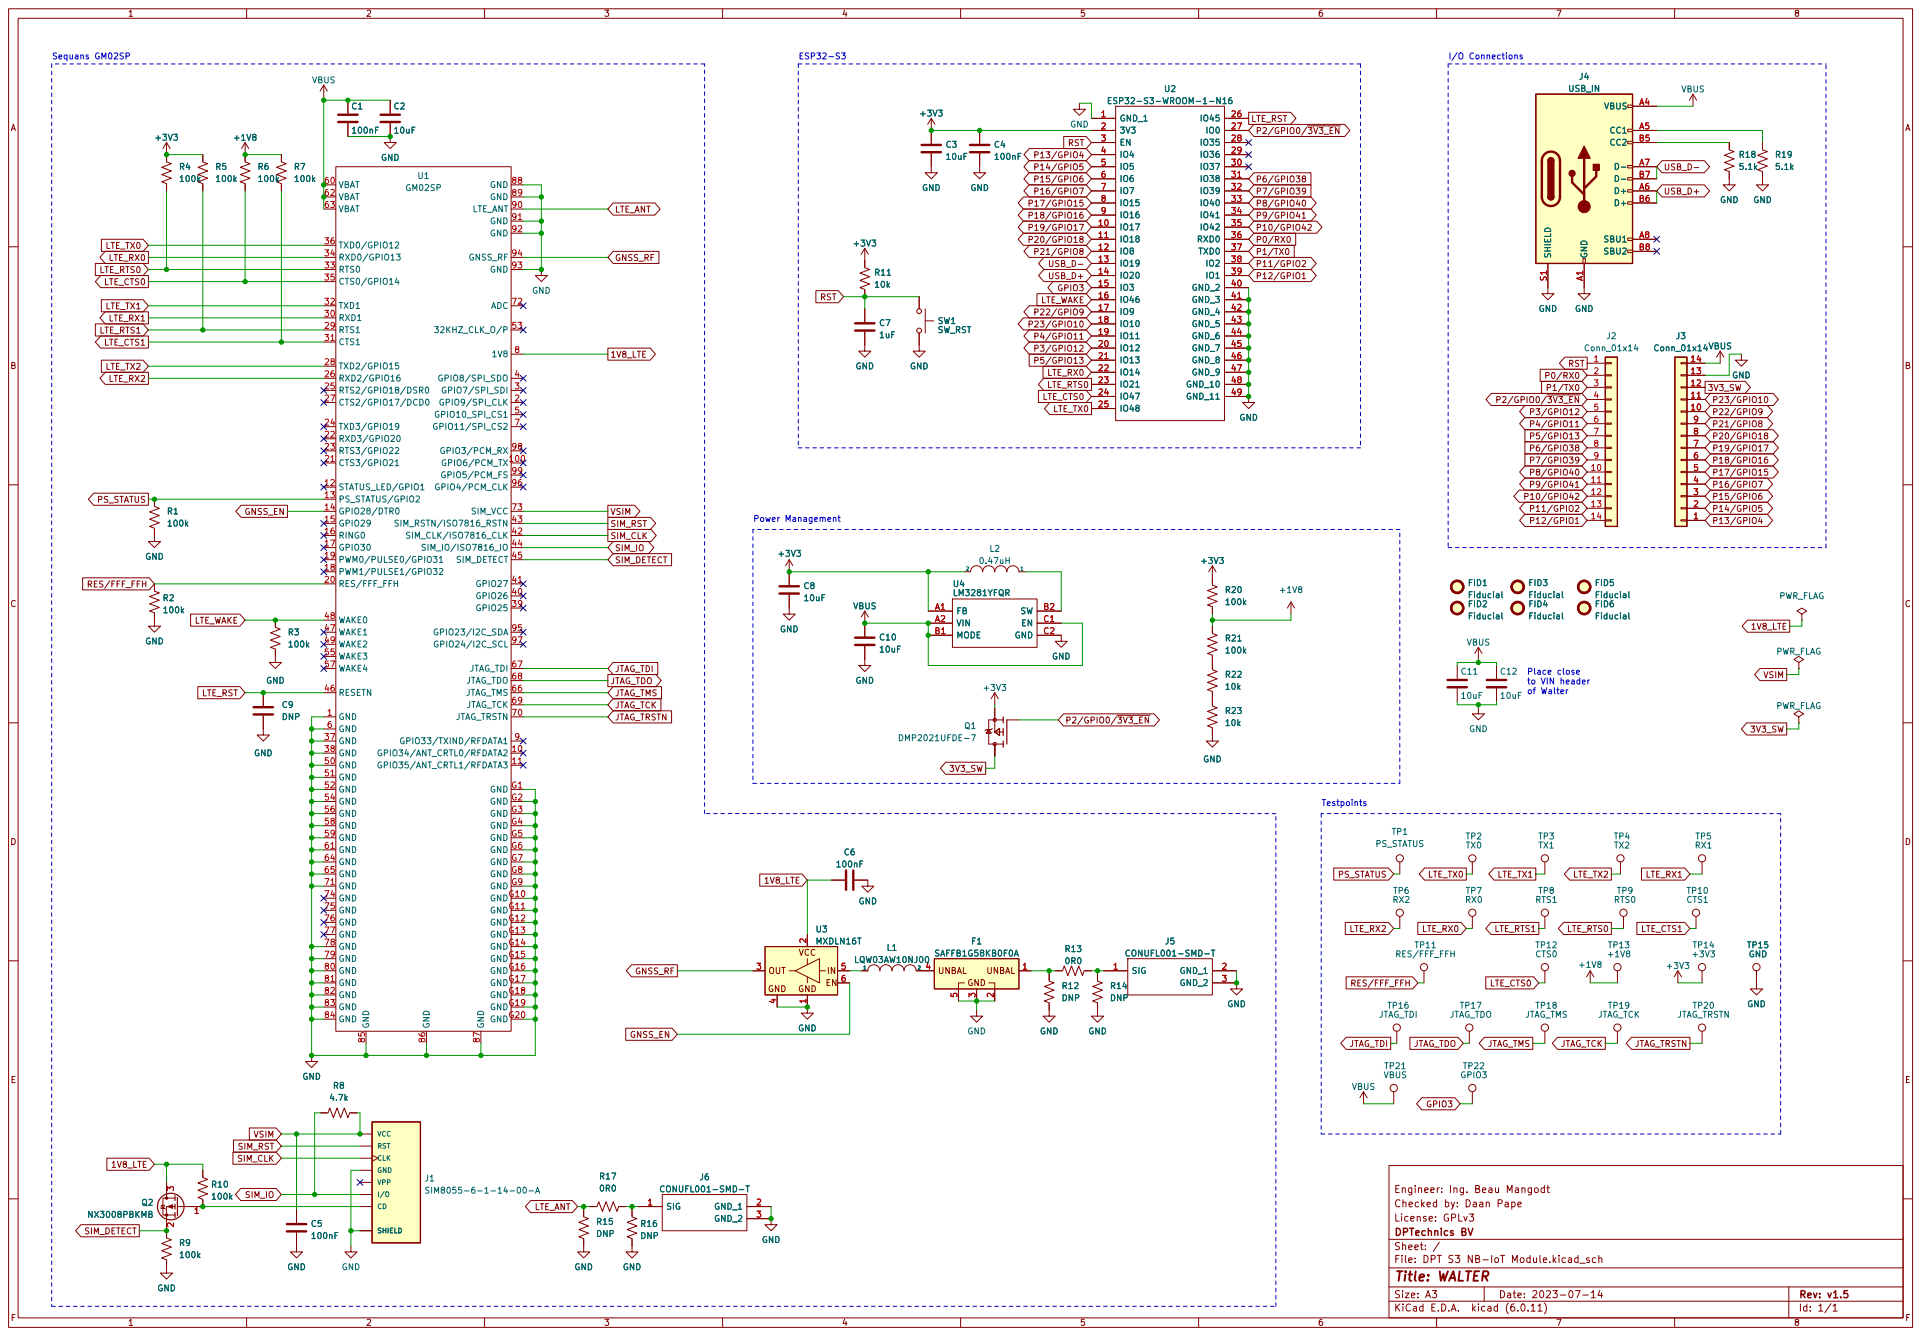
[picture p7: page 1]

to VIN header of Walter Testpoints Power Management C1

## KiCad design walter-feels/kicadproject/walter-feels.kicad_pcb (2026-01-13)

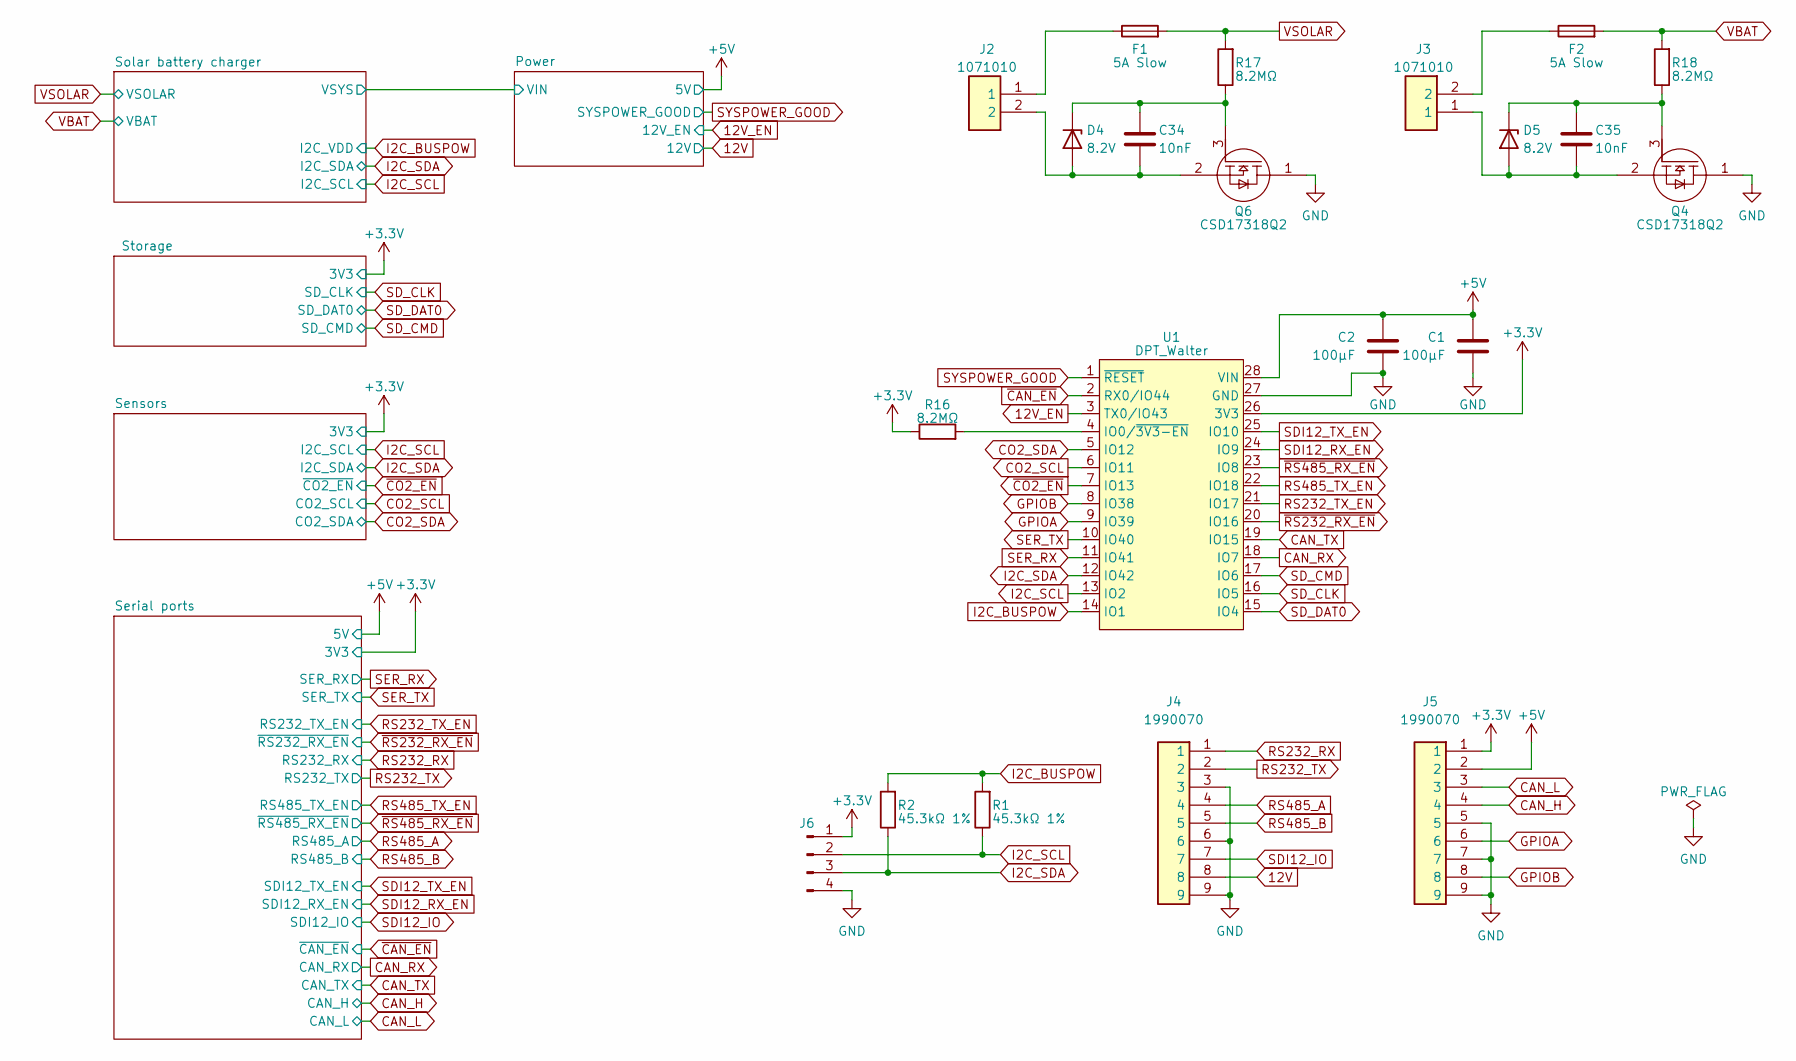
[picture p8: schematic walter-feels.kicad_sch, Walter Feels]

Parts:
C1, C2: 100µF; C_1210_3225Metric; JLCPCB C49066
C34, C35: 10nF; C_0603_1608Metric; JLCPCB C57112
D4, D5: 8.2V; D_SOD-523; PARTNO MM5Z8V2T1G; JLCPCB C99679
F1, F2: 5A Slow; Fuse_1206_3216Metric; JLCPCB C2691999
J2, J3: 1071010; JLCPCB C3310307
J4, J5: 1990070; JLCPCB C17275119
J6: Conn_01x04_Male; PinHeader_1x04_P2.54mm_Vertical; JLCPCB C5116483
Q4, Q6: CSD17318Q2
R1, R2: 45.3kΩ 1%; R_0603_1608Metric; JLCPCB C209146
R16, R17, R18: 8.2MΩ; R_0603_1608Metric; JLCPCB C13323
U1: DPT_Walter; walter-socket

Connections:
12V: J4.8; also elsewhere on the board
12V_EN: U1.3 (TX0/IO43); also elsewhere on the board
+3.3V: J5.1, J6.1, R16.1, U1.26 (3V3); also elsewhere on the board
+5V: C1.1, C2.1, J5.2, U1.28 (VIN); also elsewhere on the board
CAN_H: J5.4; also elsewhere on the board
CAN_L: J5.3; also elsewhere on the board
CAN_RX: U1.18 (IO7); also elsewhere on the board
CAN_TX: U1.19 (IO15); also elsewhere on the board
CO2_SCL: U1.6 (IO11); also elsewhere on the board
CO2_SDA: U1.5 (IO12); also elsewhere on the board
GND: C1.2, C2.2, J4.3, J4.6, J4.9, J5.5, J5.7, J5.9, J6.4, Q4.1, Q6.1, U1.27 (GND); also elsewhere on the board
GPIOA: J5.6, U1.9 (IO39)
GPIOB: J5.8, U1.8 (IO38)
I2C_BUSPOW: R1.2, R2.2, U1.14 (IO1); also elsewhere on the board
I2C_SCL: J6.2, R1.1, U1.13 (IO2); also elsewhere on the board
I2C_SDA: J6.3, R2.1, U1.12 (IO42); also elsewhere on the board
unnamed: C34.1, D4.1 (K), Q6.3, R17.1
unnamed: C34.2, D4.2 (A), J2.2, Q6.2
unnamed: C35.1, D5.1 (K), Q4.3, R18.1
unnamed: C35.2, D5.2 (A), J3.1, Q4.2
unnamed: F1.1, J2.1
unnamed: F2.1, J3.2
unnamed: R16.2, U1.4 (IO0/~3V3-EN)
RS232_RX: J4.1; also elsewhere on the board
RS232_TX: J4.2; also elsewhere on the board
RS232_TX_EN: U1.21 (IO17); also elsewhere on the board
RS485_A: J4.4; also elsewhere on the board
RS485_B: J4.5; also elsewhere on the board
RS485_TX_EN: U1.22 (IO18); also elsewhere on the board
SDI12_IO: J4.7; also elsewhere on the board
SDI12_RX_EN: U1.24 (IO9); also elsewhere on the board
SDI12_TX_EN: U1.25 (IO10); also elsewhere on the board
SD_CLK: U1.16 (IO5); also elsewhere on the board
SD_CMD: U1.17 (IO6); also elsewhere on the board
SD_DAT0: U1.15 (IO4); also elsewhere on the board
SER_RX: U1.11 (IO41); also elsewhere on the board
SER_TX: U1.10 (IO40); also elsewhere on the board
SYSPOWER_GOOD: U1.1 (~RESET); also elsewhere on the board
VBAT: F2.2, R18.2; also elsewhere on the board
VSOLAR: F1.2, R17.2; also elsewhere on the board
~CAN_EN: U1.2 (RX0/IO44); also elsewhere on the board
~CO2_EN: U1.7 (IO13); also elsewhere on the board
~RS232_RX_EN: U1.20 (IO16); also elsewhere on the board
~RS485_RX_EN: U1.23 (IO8); also elsewhere on the board

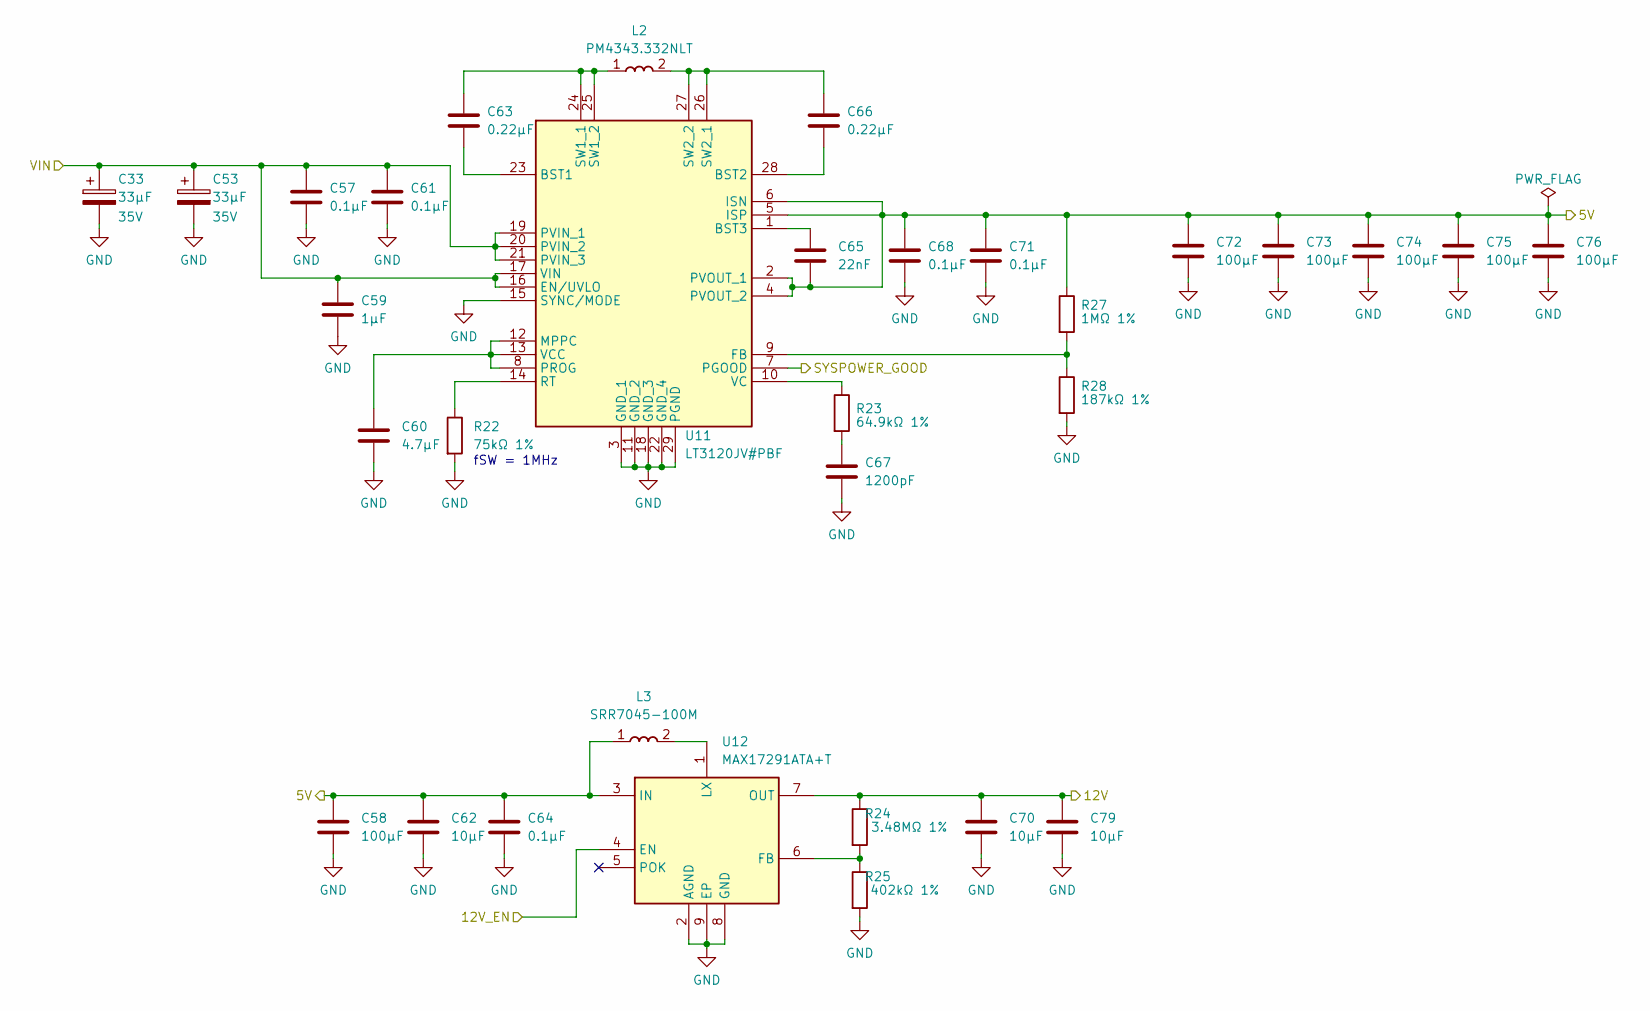
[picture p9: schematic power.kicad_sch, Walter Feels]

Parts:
C33, C53: 33µF; CP_EIA-7343-30_AVX-N; Voltage 35V; JLCPCB C2158306
C57, C61, C64, C68, C71: 0.1µF; C_0603_1608Metric; JLCPCB C14663
C58, C72, C73, C74, C75, C76: 100µF; C_1210_3225Metric; JLCPCB C49066
C59: 1μF; C_0603_1608Metric; JLCPCB C15849
C60: 4.7μF; C_0603_1608Metric; JLCPCB C19666
C62, C70, C79: 10µF; C_1206_3216Metric; JLCPCB C13585
C63, C66: 0.22µF; C_0603_1608Metric; JLCPCB C21120
C65: 22nF; C_0603_1608Metric; JLCPCB C21122
C67: 1200pF; C_0603_1608Metric; JLCPCB C30615
L2: PM4343.332NLT; INDPM140128X650N; JLCPCB C2594689
L3: SRR7045-100M; SRR7045100M; JLCPCB C1329516
R22: 75kΩ 1%; R_0603_1608Metric; JLCPCB C23242
R23: 64.9kΩ 1%; R_0603_1608Metric; JLCPCB C14891
R24: 3.48MΩ 1%; R_0603_1608Metric; JLCPCB C422936
R25: 402kΩ 1%; R_0603_1608Metric; JLCPCB C2960796
R27: 1MΩ 1%; R_0603_1608Metric; JLCPCB C22935
R28: 187kΩ 1%; R_0603_1608Metric; JLCPCB C321764
U11: LT3120JV#PBF; QFN50P400X500X83-29N-D; JLCPCB C3198178
U12: MAX17291ATA+T; SON50P200X200X80-9N-D; JLCPCB C7456683

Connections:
12V: C70.1, C79.1, R24.1, U12.7 (OUT); also elsewhere on the board
12V_EN: U12.4 (EN); also elsewhere on the board
+5V: C58.1, C62.1, C64.1, C65.2, C68.1, C71.1, C72.1, C73.1, C74.1, C75.1, C76.1, L3.1, R27.1, U11.2 (PVOUT_1), U11.4 (PVOUT_2), U11.5 (ISP), U11.6 (ISN), U12.3 (IN); also elsewhere on the board
/Power/VIN: C33.1, C53.1, C57.1, C59.2, C61.1, U11.16 (EN/UVLO), U11.17 (VIN), U11.19 (PVIN_1), U11.20 (PVIN_2), U11.21 (PVIN_3); also elsewhere on the board
GND: C33.2, C53.2, C57.2, C58.2, C59.1, C60.1, C61.2, C62.2, C64.2, C67.2, C68.2, C70.2, C71.2, C72.2, C73.2, C74.2, C75.2, C76.2, C79.2, R22.2, R25.2, R28.2, U11.3 (GND_1), U11.11 (GND_2), U11.15 (SYNC/MODE), U11.18 (GND_3), U11.22 (GND_4), U11.29 (PGND), U12.2 (AGND), U12.8 (GND), U12.9 (EP); also elsewhere on the board
unnamed: C60.2, U11.8 (PROG), U11.12 (MPPC), U11.13 (VCC)
unnamed: C63.1, L2.1, U11.24 (SW1_1), U11.25 (SW1_2)
unnamed: C63.2, U11.23 (BST1)
unnamed: C65.1, U11.1 (BST3)
unnamed: C66.1, L2.2, U11.26 (SW2_1), U11.27 (SW2_2)
unnamed: C66.2, U11.28 (BST2)
unnamed: C67.1, R23.2
unnamed: L3.2, U12.1 (LX)
unnamed: R22.1, U11.14 (RT)
unnamed: R23.1, U11.10 (VC)
unnamed: R24.2, R25.1, U12.6 (FB)
unnamed: R27.2, R28.1, U11.9 (FB)
SYSPOWER_GOOD: U11.7 (PGOOD); also elsewhere on the board

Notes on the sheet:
fSW = 1MHz

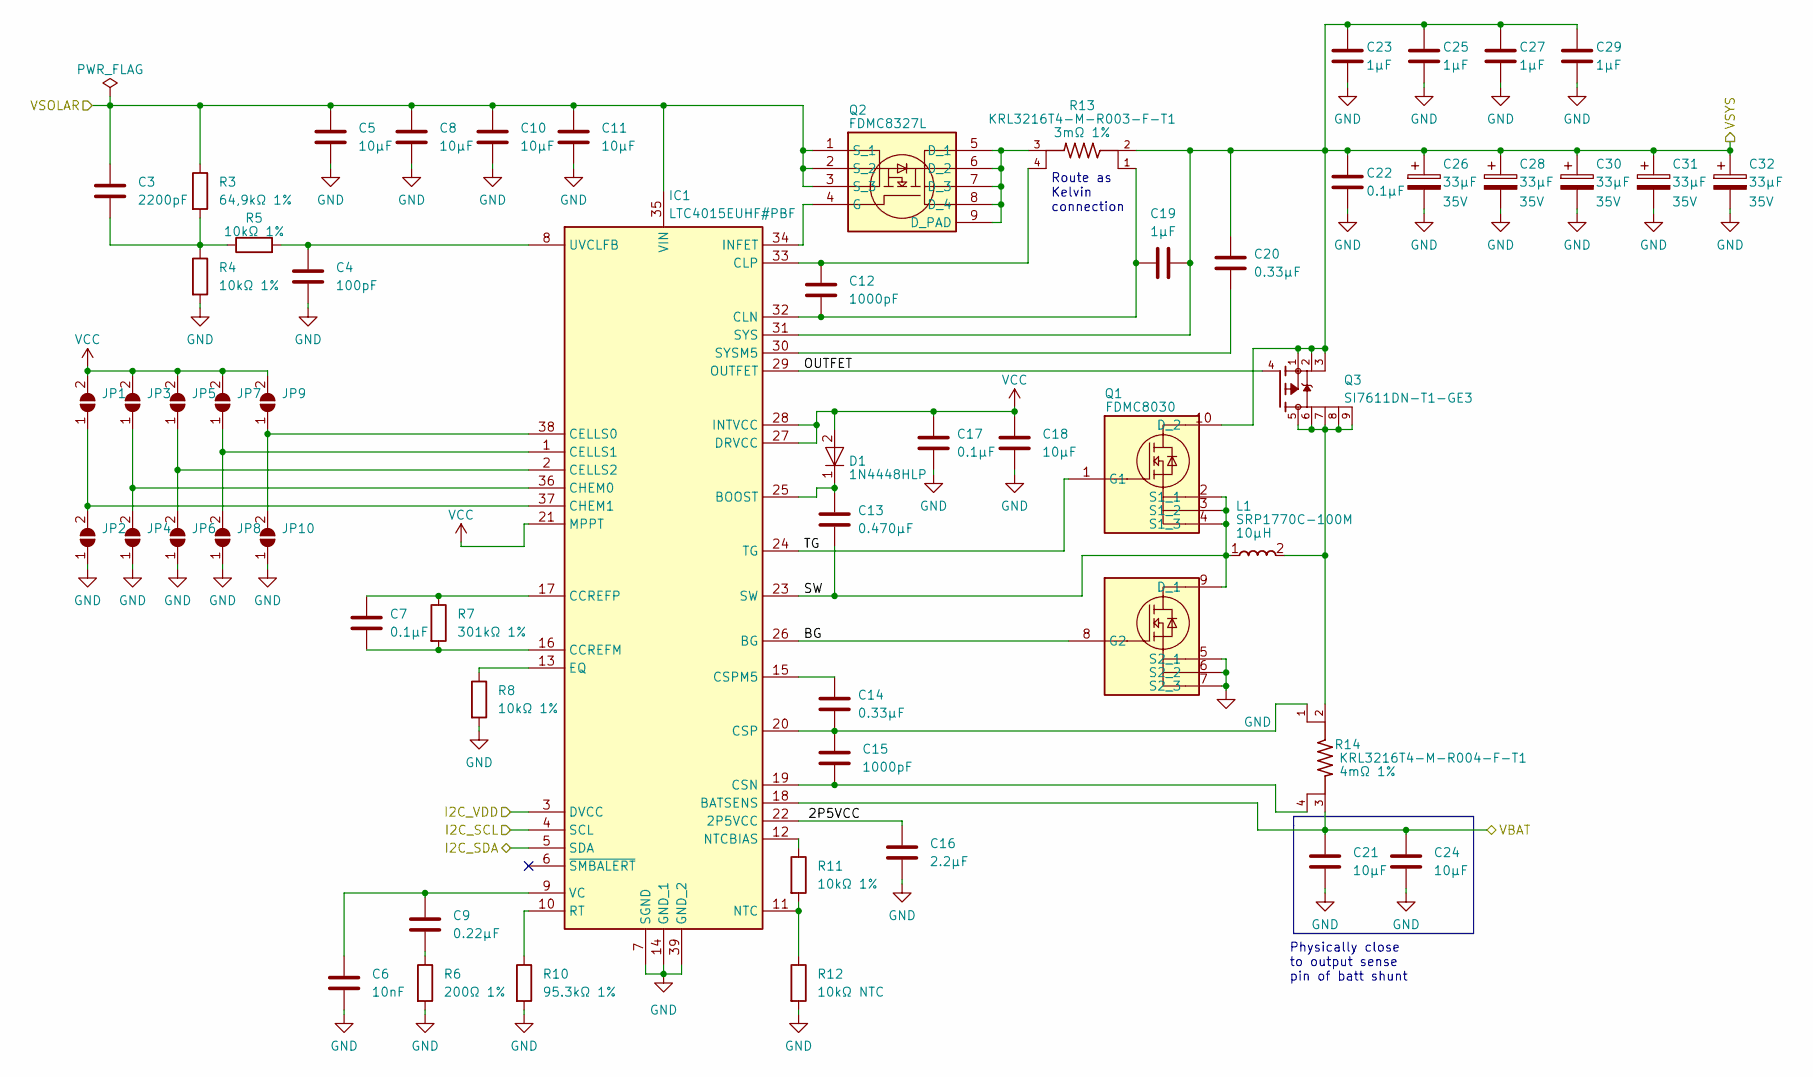
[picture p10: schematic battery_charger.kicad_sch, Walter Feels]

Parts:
C3: 2200pF; C_0603_1608Metric; JLCPCB C1604
C4: 100pF; C_0603_1608Metric; JLCPCB C14858
C5, C8, C10, C11, C18, C21, C24: 10µF; C_1206_3216Metric; JLCPCB C13585
C6: 10nF; C_0603_1608Metric; JLCPCB C57112
C7, C17, C22: 0.1µF; C_0603_1608Metric; JLCPCB C14663
C9: 0.22μF; C_0603_1608Metric; JLCPCB C21120
C12, C15: 1000pF; C_0603_1608Metric; JLCPCB C1588
C13: 0.470µF; C_0603_1608Metric; JLCPCB C1623
C14, C20: 0.33μF; C_0603_1608Metric; JLCPCB C1615
C16: 2.2μF; C_0603_1608Metric; JLCPCB C23630
C19, C23, C25, C27, C29: 1μF; C_0603_1608Metric; JLCPCB C15849
C26, C28, C30, C31, C32: 33µF; CP_EIA-7343-30_AVX-N; Voltage 35V; JLCPCB C2158306
D1: 1N4448HLP; DESD3V3S1BL7B; JLCPCB C154874
IC1: LTC4015EUHF#PBF; QFN50P500X700X80-39N-D; Manufacturer_Part_Number LTC4015EUHF#PBF; Mouser Part Number 584-LTC4015EUHF#PBF
JP1, JP2, JP3, JP4, JP5, JP6, JP7, JP8, JP9, JP10: SolderJumper_2_Open; SolderJumper-2_P1.3mm_Open_TrianglePad1.0x1.5mm
L1: SRP1770C-100M; INDPM178169X700N; JLCPCB C1331642
Q1: FDMC8030; FDMC89521L; JLCPCB C890952
Q2: FDMC8327L; FDMC86139P; Mouser Part Number 512-FDMC8327L
Q3: SI7611DN-T1-GE3; VISHAY_SIS468DN-T1-GE3; JLCPCB C506599
R3: 64,9kΩ 1%; R_0603_1608Metric; JLCPCB C137810
R4, R5, R8, R11: 10kΩ 1%; R_0603_1608Metric; JLCPCB C25804
R6: 200Ω 1%; R_0603_1608Metric; JLCPCB C8218
R7: 301kΩ 1%; R_0603_1608Metric; JLCPCB C177982
R10: 95.3kΩ 1%; R_0603_1608Metric; JLCPCB C23267
R12: 10kΩ NTC; R_0603_1608Metric; JLCPCB C13564
R13: KRL3216T4-M-R003-F-T1; RES_KRL3216T4-M-R003-F-T1; JLCPCB C4119998
R14: KRL3216T4-M-R004-F-T1; RES_KRL3216T4-M-R003-F-T1; JLCPCB C2090348

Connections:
/Power/VIN: C19.2, C20.2, C22.1, C23.2, C25.2, C26.1, C27.2, C28.1, C29.2, C30.1, C31.1, C32.1, IC1.31 (SYS), Q1.10 (D_2), Q3.1, Q3.2, Q3.3, R13.2; also elsewhere on the board
/Solar battery charger/2P5VCC: C16.1, IC1.22 (2P5VCC)
/Solar battery charger/BG: IC1.26 (BG), Q1.8 (G2)
/Solar battery charger/OUTFET: IC1.29 (OUTFET), Q3.4
/Solar battery charger/SW: C13.2, IC1.23 (SW), L1.1, Q1.2 (S1_1), Q1.3 (S1_2), Q1.4 (S1_3), Q1.9 (D_1)
/Solar battery charger/TG: IC1.24 (TG), Q1.1 (G1)
GND: C4.2, C5.2, C6.2, C8.2, C10.2, C11.2, C16.2, C17.2, C18.2, C21.2, C22.2, C23.1, C24.2, C25.1, C26.2, C27.1, C28.2, C29.1, C30.2, C31.2, C32.2, IC1.7 (SGND), IC1.14 (GND_1), IC1.39 (GND_2), JP2.1 (A), JP4.1 (A), JP6.1 (A), JP8.1 (A), JP10.1 (A), Q1.5 (S2_1), Q1.6 (S2_2), Q1.7 (S2_3), R4.2, R6.2, R8.2, R10.2, R12.2; also elsewhere on the board
I2C_BUSPOW: IC1.3 (DVCC); also elsewhere on the board
I2C_SCL: IC1.4 (SCL); also elsewhere on the board
I2C_SDA: IC1.5 (SDA); also elsewhere on the board
unnamed: C3.2, R3.2, R4.1, R5.1
unnamed: C4.1, IC1.8 (UVCLFB), R5.2
unnamed: C6.1, C9.1, IC1.9 (VC)
unnamed: C7.1, IC1.17 (CCREFP), R7.1
unnamed: C7.2, IC1.16 (CCREFM), R7.2
unnamed: C9.2, R6.1
unnamed: C12.1, IC1.33 (CLP), R13.4
unnamed: C12.2, C19.1, IC1.32 (CLN), R13.1
unnamed: C13.1, D1.1 (K), IC1.25 (BOOST)
unnamed: C14.1, C15.1, IC1.20 (CSP), R14.1
unnamed: C14.2, IC1.15 (CSPM5)
unnamed: C15.2, IC1.19 (CSN), R14.4
unnamed: C20.1, IC1.30 (SYSM5)
unnamed: IC1.1 (CELLS1), JP7.1 (A), JP8.2 (B)
unnamed: IC1.2 (CELLS2), JP5.1 (A), JP6.2 (B)
unnamed: IC1.10 (RT), R10.1
unnamed: IC1.11 (NTC), R11.2, R12.1
unnamed: IC1.12 (NTCBIAS), R11.1
unnamed: IC1.13 (EQ), R8.1
unnamed: IC1.34 (INFET), Q2.4 (G)
unnamed: IC1.36 (CHEM0), JP3.1 (A), JP4.2 (B)
unnamed: IC1.37 (CHEM1), JP1.1 (A), JP2.2 (B)
unnamed: IC1.38 (CELLS0), JP9.1 (A), JP10.2 (B)
unnamed: L1.2, Q3.5, Q3.6, Q3.7, Q3.8, Q3.9, R14.2
unnamed: Q2.5 (D_1), Q2.6 (D_2), Q2.7 (D_3), Q2.8 (D_4), Q2.9 (D_PAD), R13.3
VBAT: C21.1, C24.1, IC1.18 (BATSENS), R14.3; also elsewhere on the board
VCC: C17.1, C18.1, D1.2 (A), IC1.21 (MPPT), IC1.27 (DRVCC), IC1.28 (INTVCC), JP1.2 (B), JP3.2 (B), JP5.2 (B), JP7.2 (B), JP9.2 (B)
VSOLAR: C3.1, C5.1, C8.1, C10.1, C11.1, IC1.35 (VIN), Q2.1 (S_1), Q2.2 (S_2), Q2.3 (S_3), R3.1; also elsewhere on the board

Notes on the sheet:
Route as Kelvin connection
Physically close to output sense pin of batt shunt

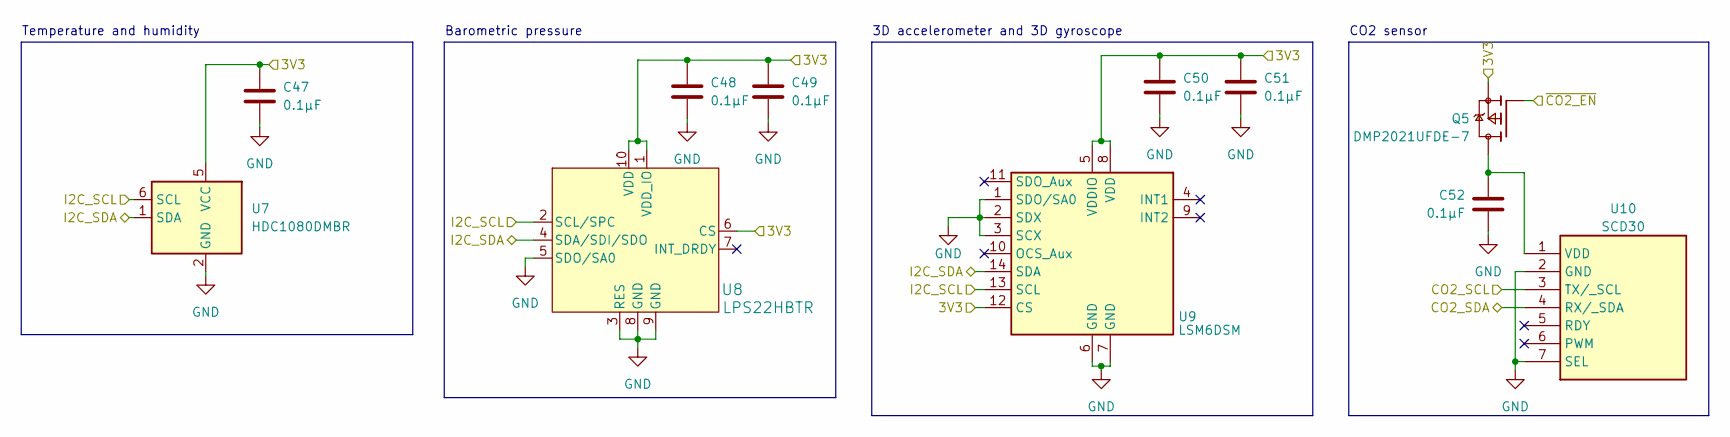
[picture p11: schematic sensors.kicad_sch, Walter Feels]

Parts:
C47, C48, C49, C50, C51, C52: 0.1µF; C_0603_1608Metric; JLCPCB C14663
Q5: DMP2021UFDE-7; MOSFET_DMP2066UFDE-7; JLCPCB C151459
U7: HDC1080DMBR; Texas_PWSON-N6; JLCPCB C82227
U8: LPS22HBTR; HLGA10_2X2_STM-L; JLCPCB C94049
U9: LSM6DSM; LGA-14_3x2.5mm_P0.5mm_LayoutBorder3x4y; JLCPCB C94048
U10: SCD30; JLCPCB C1519271

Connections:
+3.3V: C47.1, C48.1, C49.1, C50.1, C51.1, Q5.4, Q5.7, U7.5 (VCC), U8.1 (VDD_IO), U8.6 (CS), U8.10 (VDD), U9.5 (VDDIO), U9.8 (VDD), U9.12 (CS); also elsewhere on the board
CO2_SCL: U10.3 (TX/_SCL); also elsewhere on the board
CO2_SDA: U10.4 (RX/_SDA); also elsewhere on the board
GND: C47.2, C48.2, C49.2, C50.2, C51.2, C52.2, U7.2 (GND), U8.3 (RES), U8.5 (SDO/SA0), U8.8 (GND), U8.9 (GND), U9.1 (SDO/SA0), U9.2 (SDX), U9.3 (SCX), U9.6 (GND), U9.7 (GND), U10.2 (GND), U10.7 (SEL); also elsewhere on the board
I2C_SCL: U7.6 (SCL), U8.2 (SCL/SPC), U9.13 (SCL); also elsewhere on the board
I2C_SDA: U7.1 (SDA), U8.4 (SDA/SDI/SDO), U9.14 (SDA); also elsewhere on the board
unnamed: C52.1, Q5.1, Q5.2, Q5.5, Q5.6, U10.1 (VDD)
~CO2_EN: Q5.3; also elsewhere on the board

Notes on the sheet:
Barometric pressure
Temperature and humidity
3D accelerometer and 3D gyroscope
CO2 sensor

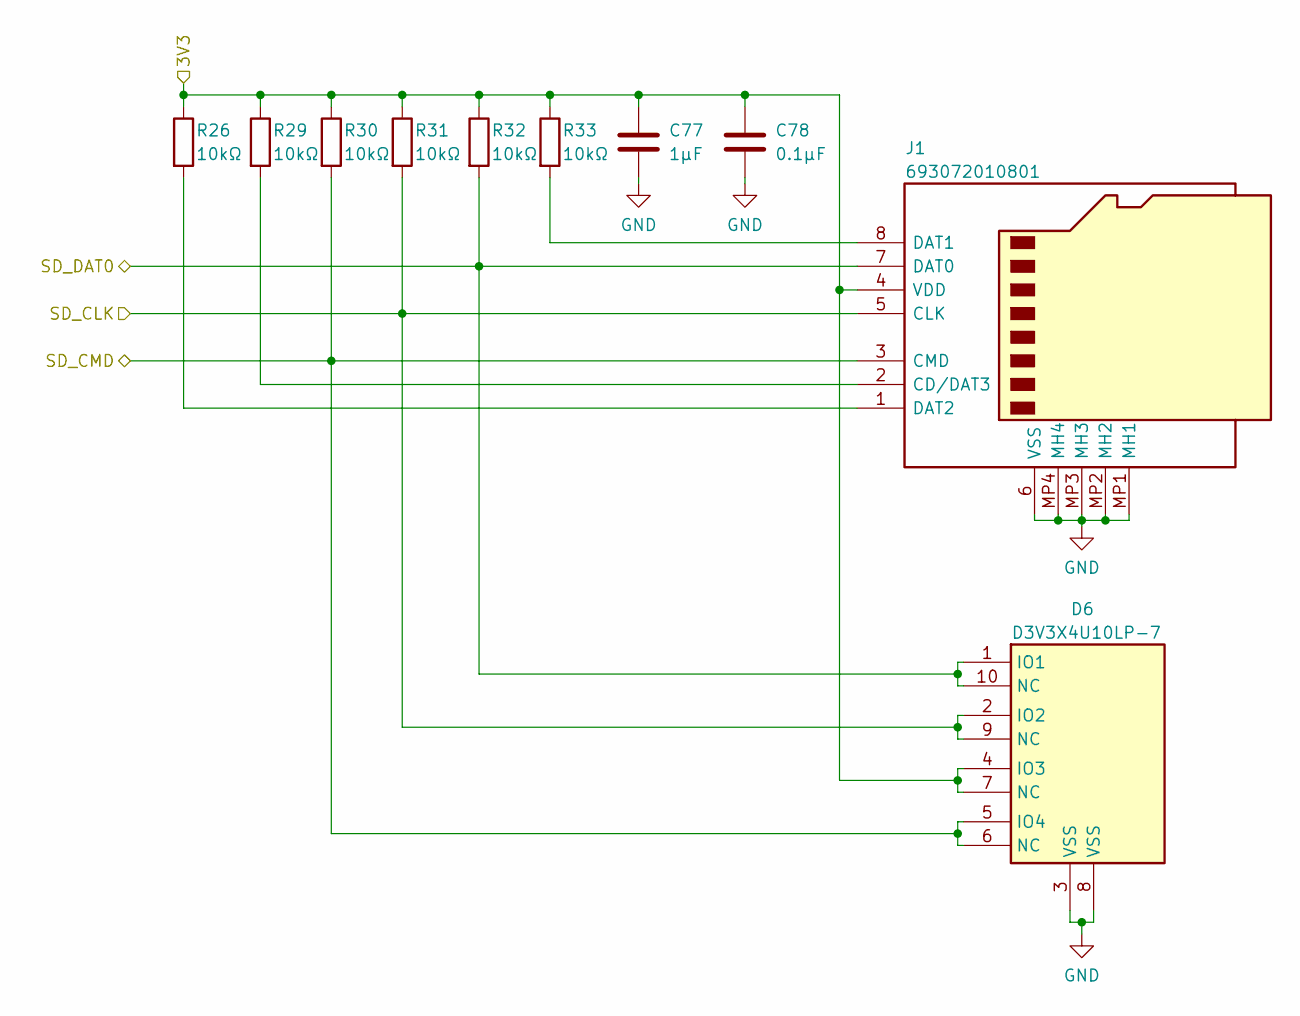
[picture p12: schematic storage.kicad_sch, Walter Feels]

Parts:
C77: 1μF; C_0603_1608Metric; JLCPCB C15849
C78: 0.1µF; C_0603_1608Metric; JLCPCB C14663
D6: D3V3X4U10LP-7; D3V3X4U10LP7; JLCPCB C1974550
J1: 693072010801; JLCPCB C5912397
R26, R29, R30, R31, R32, R33: 10kΩ; R_0603_1608Metric; JLCPCB C25804

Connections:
+3.3V: C77.2, C78.1, D6.4 (IO3), D6.7 (NC), J1.4 (VDD), R26.1, R29.1, R30.1, R31.1, R32.1, R33.1; also elsewhere on the board
GND: C77.1, C78.2, D6.3 (VSS), D6.8 (VSS), J1.6 (VSS), J1.MP1 (MH1), J1.MP2 (MH2), J1.MP3 (MH3), J1.MP4 (MH4); also elsewhere on the board
unnamed: J1.1 (DAT2), R26.2
unnamed: J1.2 (CD/DAT3), R29.2
unnamed: J1.8 (DAT1), R33.2
SD_CLK: D6.2 (IO2), D6.9 (NC), J1.5 (CLK), R31.2; also elsewhere on the board
SD_CMD: D6.5 (IO4), D6.6 (NC), J1.3 (CMD), R30.2; also elsewhere on the board
SD_DAT0: D6.1 (IO1), D6.10 (NC), J1.7 (DAT0), R32.2; also elsewhere on the board

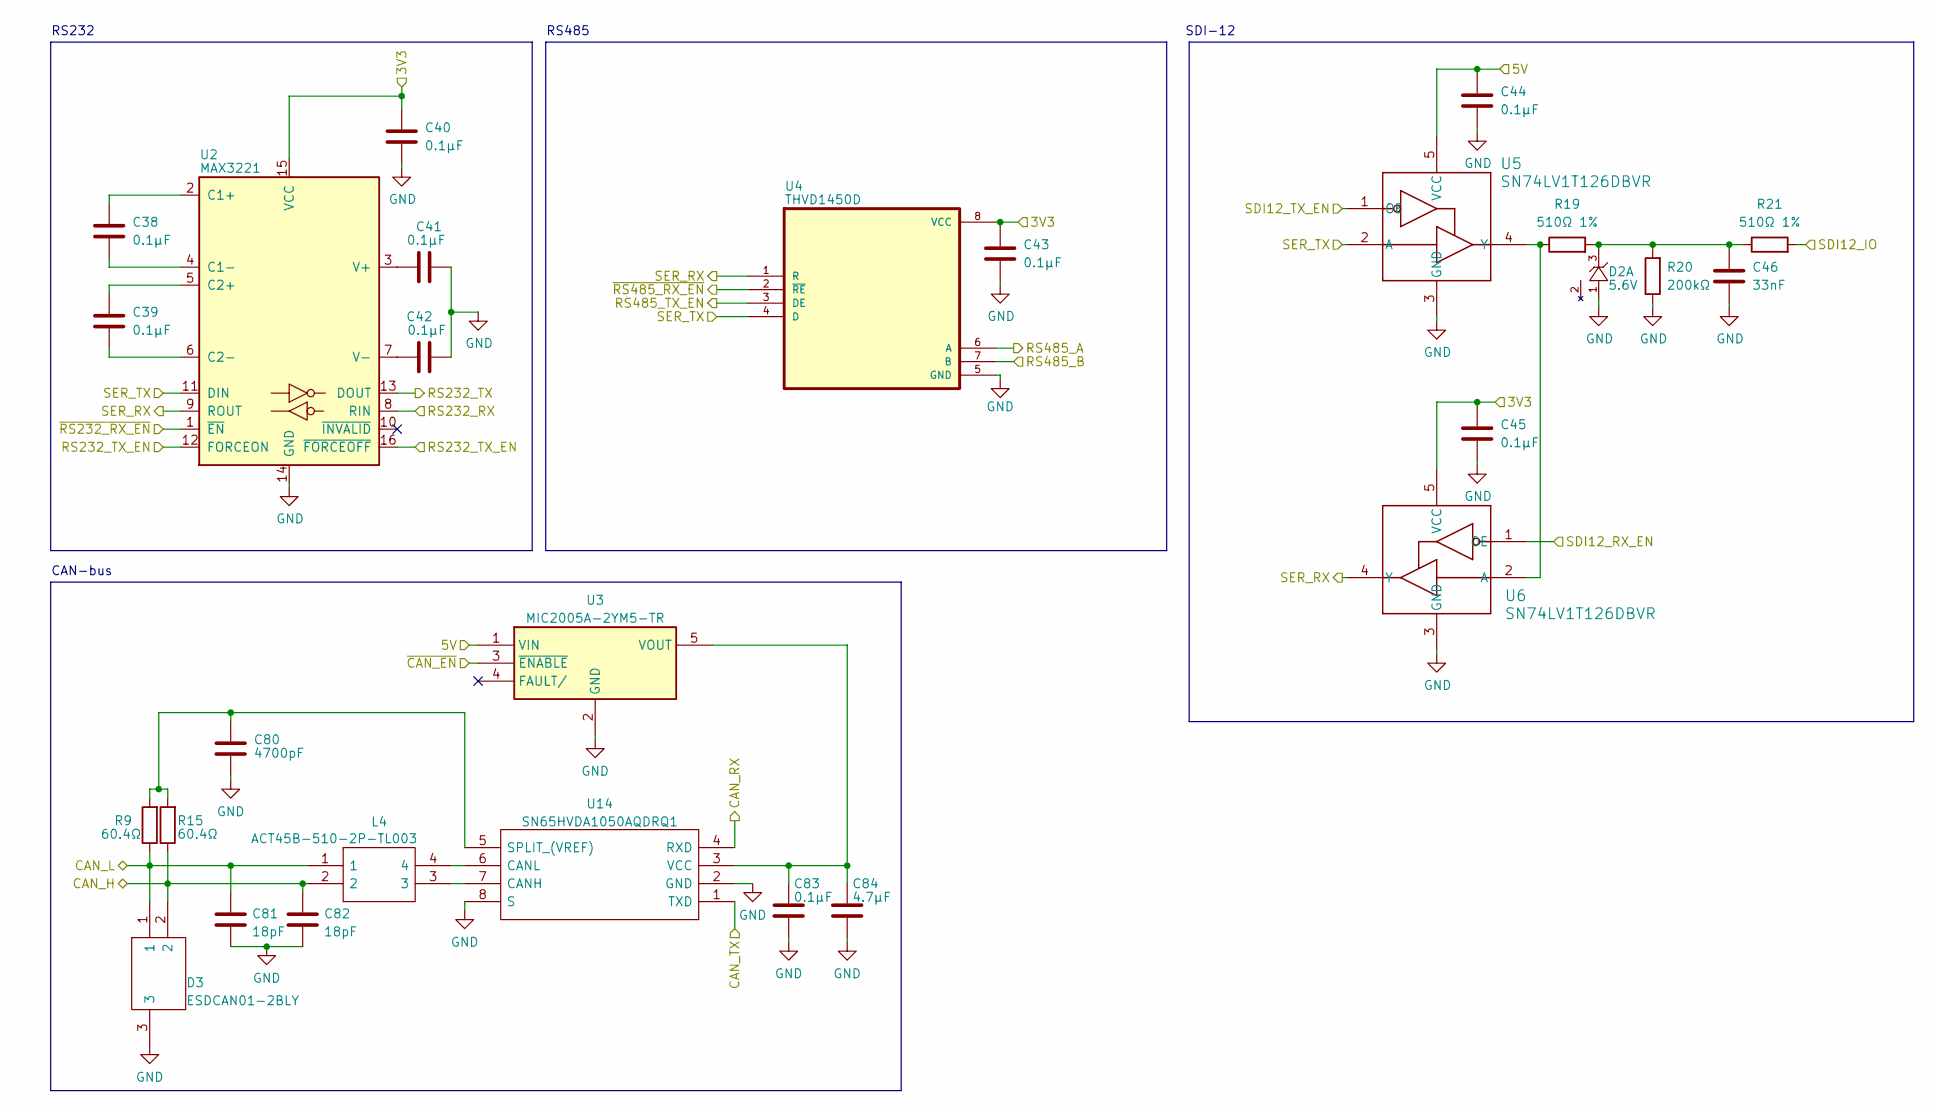
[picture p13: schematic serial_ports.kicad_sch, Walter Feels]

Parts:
C38, C39, C40, C41, C42, C43, C44, C45, C83: 0.1µF; C_0603_1608Metric; JLCPCB C14663
C46: 33nF; C_0603_1608Metric; JLCPCB C21117
C80: 4700pF; C_0603_1608Metric; JLCPCB C53987
C81, C82: 18pF; C_0603_1608Metric; JLCPCB C1647
C84: 4.7μF; C_0603_1608Metric; JLCPCB C19666
D2: 5.6V; BZX84C5V6LT1G; PartNo BZX84C5V6LT1G; JLCPCB C82471
D3: ESDCAN01-2BLY; SOT95P255X150-3N; JLCPCB C1976606
L4: ACT45B-510-2P-TL003; ACT45B1012PTL003; JLCPCB C76584
R9, R15: 60.4Ω; R_0603_1608Metric; JLCPCB C2933247
R19, R21: 510Ω 1%; R_0603_1608Metric; JLCPCB C23193
R20: 200kΩ; R_0603_1608Metric; JLCPCB C25811
U2: MAX3221; SOP65P640X110-16N; Partno MAX3221IPWR; JLCPCB C44383
U3: MIC2005A-2YM5-TR; MIC2005A-2YM5; JLCPCB C625654
U4: THVD1450D; SOIC127P599X175-8N; JLCPCB C2671361
U5, U6: SN74LV1T126DBVR; DBV0005A_N; JLCPCB C23654
U14: SN65HVDA1050AQDRQ1; SOIC127P600X175-8N; JLCPCB C115764

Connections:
+3.3V: C40.1, C43.1, C45.1, U2.15 (VCC), U4.8 (VCC), U6.5 (VCC); also elsewhere on the board
+5V: C44.1, U3.1 (VIN), U5.5 (VCC); also elsewhere on the board
CAN_H: C82.1, D3.2, L4.2, R15.1; also elsewhere on the board
CAN_L: C81.1, D3.1, L4.1, R9.1; also elsewhere on the board
CAN_RX: U14.4 (RXD); also elsewhere on the board
CAN_TX: U14.1 (TXD); also elsewhere on the board
GND: C40.2, C41.1, C42.2, C43.2, C44.2, C45.2, C46.2, C80.2, C81.2, C82.2, C83.2, C84.1, D2.1 (A), D3.3, R20.1, U2.14 (GND), U3.2 (GND), U4.5 (GND), U5.3 (GND), U6.3 (GND), U14.2 (GND), U14.8 (S); also elsewhere on the board
unnamed: C38.1, U2.2 (C1+)
unnamed: C38.2, U2.4 (C1-)
unnamed: C39.1, U2.5 (C2+)
unnamed: C39.2, U2.6 (C2-)
unnamed: C41.2, U2.3 (V+)
unnamed: C42.1, U2.7 (V-)
unnamed: C46.1, D2.3 (K), R19.2, R20.2, R21.1
unnamed: C80.1, R9.2, R15.2, U14.5 (SPLIT_(VREF))
unnamed: C83.1, C84.2, U3.5 (VOUT), U14.3 (VCC)
unnamed: L4.3, U14.7 (CANH)
unnamed: L4.4, U14.6 (CANL)
unnamed: R19.1, U5.4 (Y), U6.2 (A)
RS232_RX: U2.8 (RIN); also elsewhere on the board
RS232_TX: U2.13 (DOUT); also elsewhere on the board
RS232_TX_EN: U2.12 (FORCEON), U2.16 (~FORCEOFF); also elsewhere on the board
RS485_A: U4.6 (A); also elsewhere on the board
RS485_B: U4.7 (B); also elsewhere on the board
RS485_TX_EN: U4.3 (DE); also elsewhere on the board
SDI12_IO: R21.2; also elsewhere on the board
SDI12_RX_EN: U6.1 (OE); also elsewhere on the board
SDI12_TX_EN: U5.1 (OE); also elsewhere on the board
SER_RX: U2.9 (ROUT), U4.1 (R), U6.4 (Y); also elsewhere on the board
SER_TX: U2.11 (DIN), U4.4 (D), U5.2 (A); also elsewhere on the board
~CAN_EN: U3.3 (~ENABLE); also elsewhere on the board
~RS232_RX_EN: U2.1 (~EN); also elsewhere on the board
~RS485_RX_EN: U4.2 (~RE); also elsewhere on the board

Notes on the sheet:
CAN-bus
RS232
SDI-12
RS485

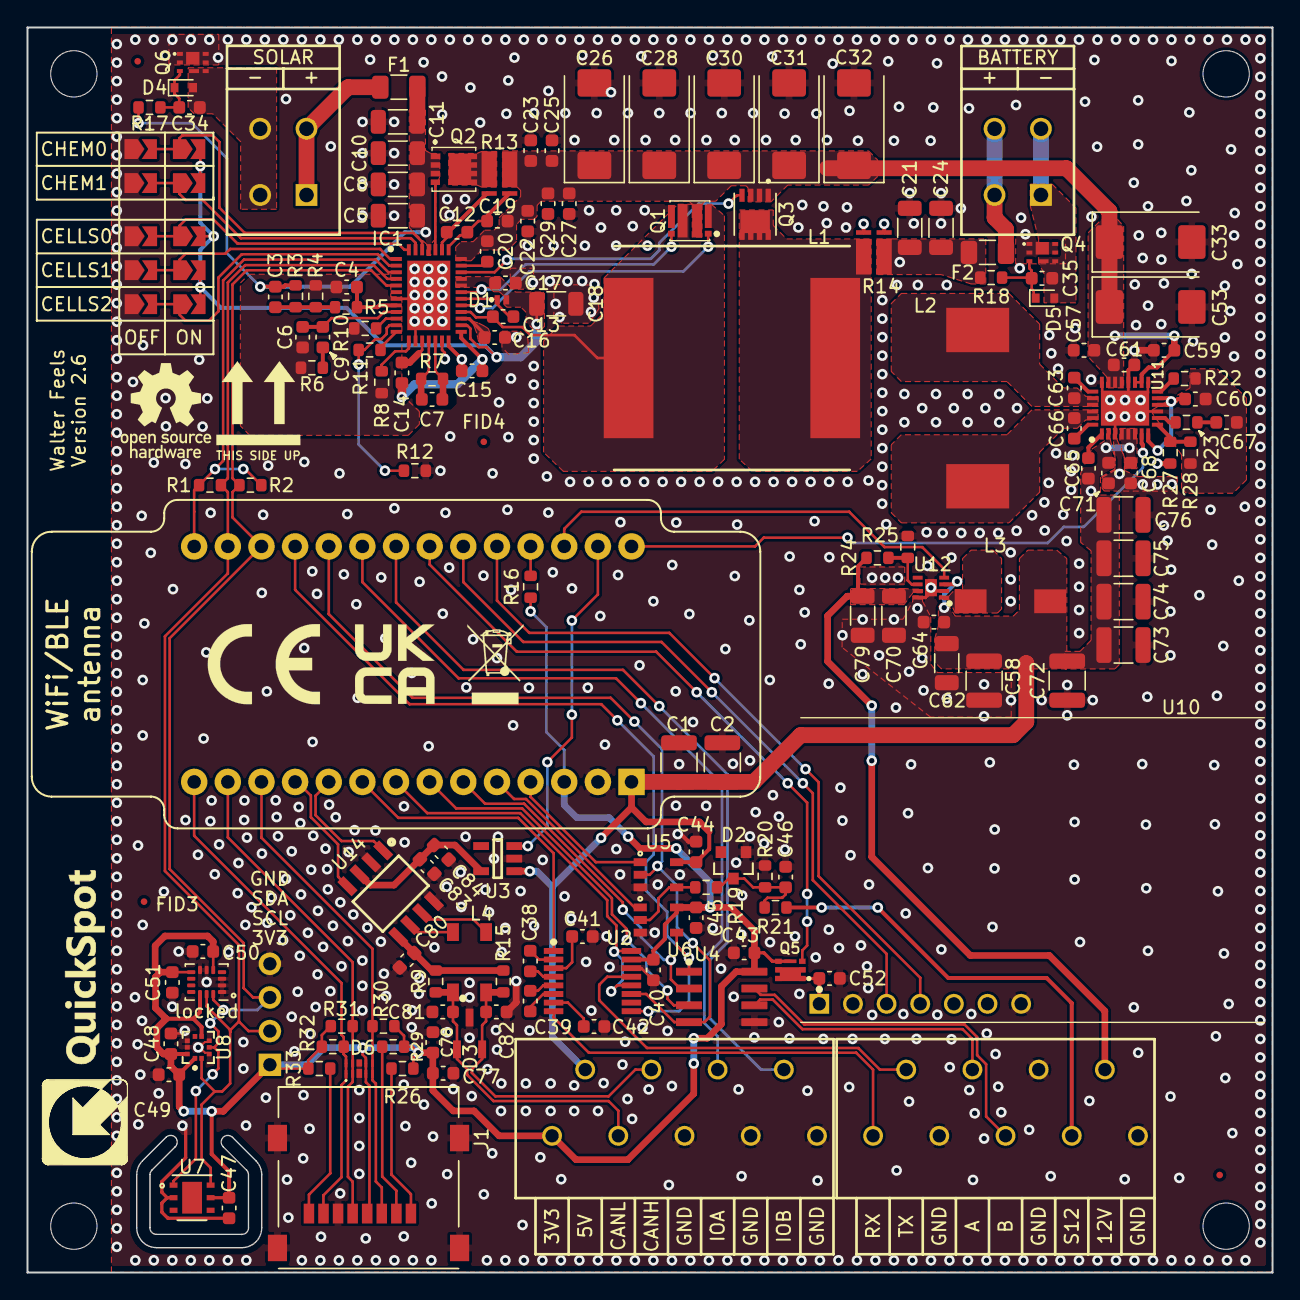
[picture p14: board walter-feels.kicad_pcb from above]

Board: 4 copper layers, 94.0 x 94.0 mm, 167 parts (0 on the bottom side), 104 nets.

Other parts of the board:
FID1, FID2, FID3, FID4: Fiducial; Fiducial_0.5mm_Mask1mm
H1, H2, H3, H4: MountingHole; MountingHole_2.7mm_M2.5_ISO14580
locked: LSM6DSM; LGA-14_3x2.5mm_P0.5mm_LayoutBorder3x4y

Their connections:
+3.3V: locked.5 (VDDIO), locked.8 (VDD), locked.12 (CS); also elsewhere on the board
GND: locked.1 (SDO/SA0), locked.2 (SDX), locked.3 (SCX), locked.6 (GND), locked.7 (GND); also elsewhere on the board
I2C_SCL: locked.13 (SCL); also elsewhere on the board
I2C_SDA: locked.14 (SDA); also elsewhere on the board

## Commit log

2023-05-11 Fixed missing pad 20 in footprints
2023-07-10 Updated datasheet with the correct pinout and pin descriptions
2023-07-10 Fixed mirrored pinout on Walter symbol in KiCAD
2023-10-06 Initial draft release of the Walter Feels expansion board
    [battery_charger.kicad_sch, power.kicad_sch, sensors.kicad_sch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]
2023-10-13 Updated Walter schematic to v1.5 and updated Walter Feels to version 2.1
    [battery_charger.kicad_sch, power.kicad_sch, sensors.kicad_sch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]
2024-03-27 Added final V1.6 schematic
    The schematic of final version v1.6 was not yet added to the repository.
2024-05-31 Added extra PCB receptacles for Walter
2024-12-05 Updated Walter Feels to V2.3
    [battery_charger.kicad_sch, power.kicad_sch, sensors.kicad_sch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]
2025-02-12 Updated to version 2.4
    [battery_charger.kicad_sch, power.kicad_sch, sensors.kicad_sch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]
2025-05-19 add 2D laser cut outlines and readme for housing prototyping
2025-12-19 Fixed pin 10 (IO40), it was set as input only but it is bidirectional
2026-01-13 Updated Walter Feels project to version 2.6
    [battery_charger.kicad_sch, power.kicad_sch, sensors.kicad_sch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]
2026-08-29 Added Altium Designer Libraries with SCH Symbol and Footprint
    Updated README with instructions on usage
    [LIB-200-009-01.SchLib, LIB-300-009-01.PcbLib]
2026-09-16 Updated datasheet to version 1.0 with MSL level information and soldering reflow profile
2026-10-16 Changes (see earlier comment)
    - Rename files to more clear names
    - Add 3D models for sockets
    - Add a solder version without sockets
    - Add TX0/RX0 on pins IO43/IO44
    - Add electrical types to I/O pins and RST pin
    - Add active low indication (for RST and DFU)

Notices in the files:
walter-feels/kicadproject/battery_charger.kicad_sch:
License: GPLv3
